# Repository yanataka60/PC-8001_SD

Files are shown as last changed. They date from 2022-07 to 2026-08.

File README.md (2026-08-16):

# PC-8001にSD-CARDからCMT形式ファイルのロード、セーブ機能

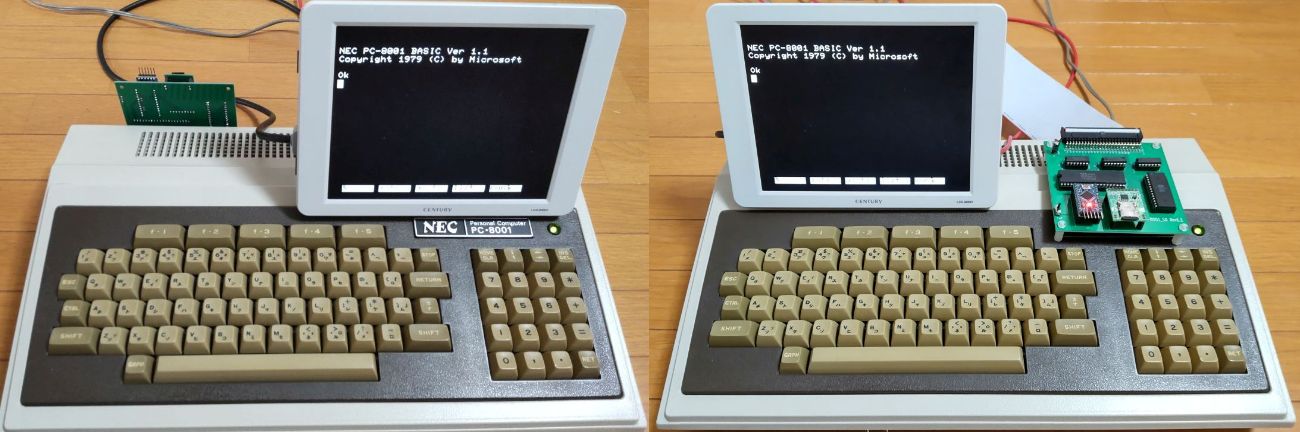
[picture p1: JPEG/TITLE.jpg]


　PC-8001でSD-CARDからCMT形式ファイルのロード、セーブ機能を実現するものです。

　CMTからの読み込み実行に数分掛かっていたゲームも数十秒で実行できます。

　接続は、PC-8001本体後ろの拡張端子に接続しますが、50pフラットケーブルでの接続、50pカードエッジコネクタでの接続のどちらかを選択できます。

　なお、Arduino、ROMへ書き込むための機器が別途必要となります。

## 回路図
　KiCadフォルダ内のPC-8001_SD.pdfを参照してください。

　J5 2x25Pinコネクタを追加しています。

[回路図](https://github.com/yanataka60/PC-8001_SD/blob/main/Kicad/PC-8001_SD.pdf)

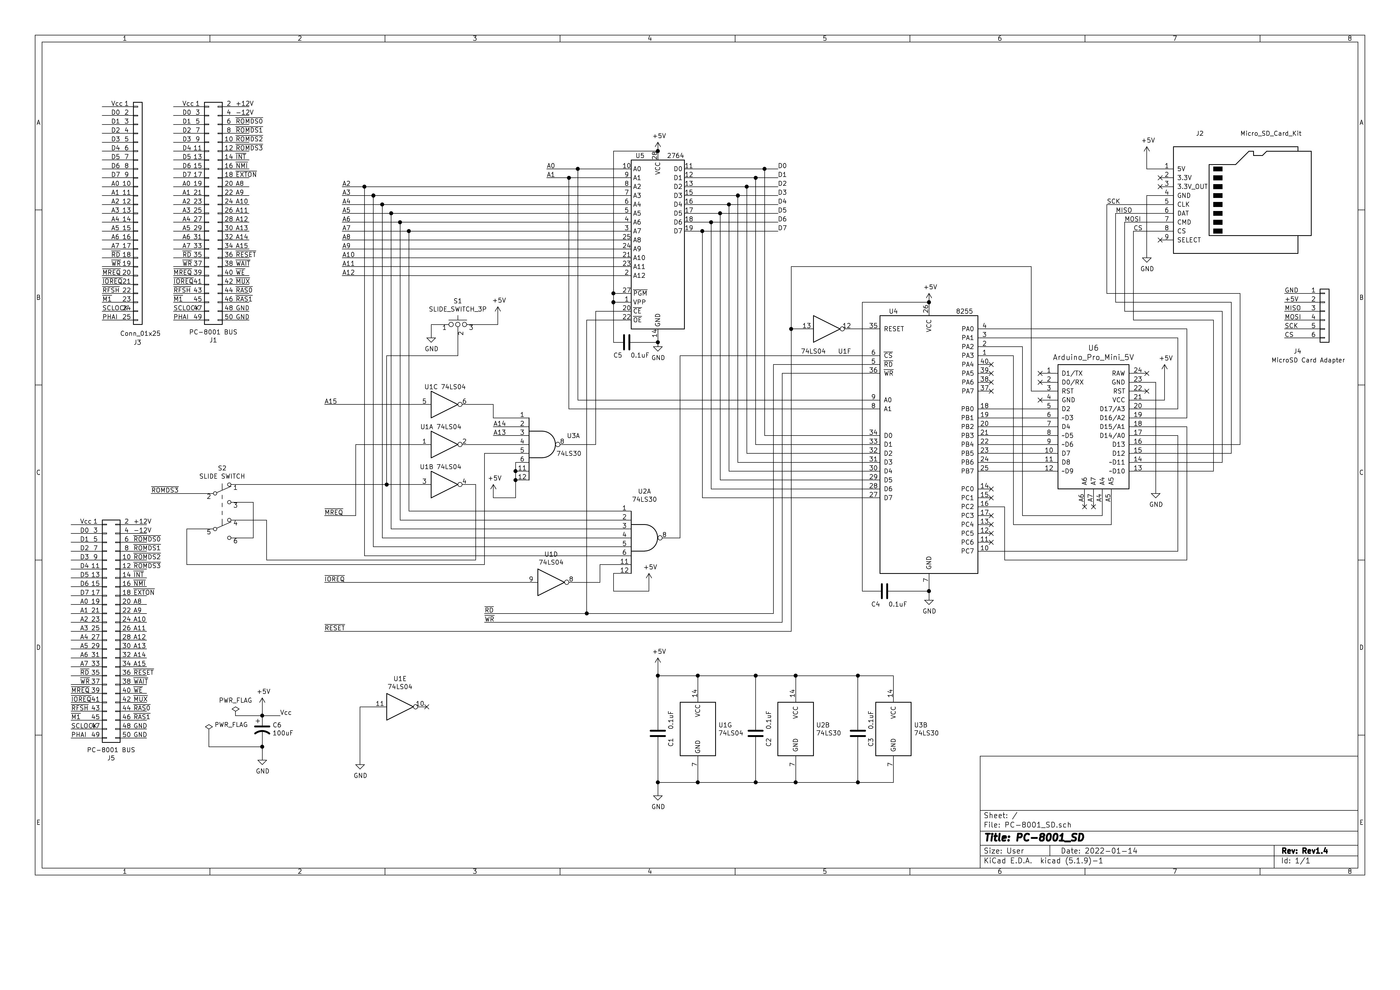
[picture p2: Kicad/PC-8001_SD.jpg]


## 部品
|番号|品名|数量|備考|
| --- | --- | --- | --- |
||J1、J3のいずれか|||
|J1|2x25ボックスヘッダ|1|共立エレショップ JS-1200R-50など、秋月電子通商 PH-2x40RGなどのピンヘッダでも代用可(注1)(注5)|
|J3|50Pカードエッジコネクタ|1|せんごくネット通販 HRS CR22A-50D-2.54DSなど(注1)|
||J2、J4のいずれか|||
|J2|Micro_SD_Card_Kit|1|秋月電子通商 AE-microSD-LLCNV (注2) (注4)|
|J4|MicroSD Card Adapter|1|Arduino等に使われる5V電源に対応したもの (注4)|
|U1|74LS04|1||
|U2 U3|74LS30|2||
|U4|8255|1||
|U5|2764/28C64相当品|1||
|U6|Arduino_Pro_Mini_5V|1|Atmega328版を使用 168版は不可。(注3)|
|C1-C5|積層セラミックコンデンサ 0.1uF|5||
|C6|電解コンデンサ 16v100uF|1||
|S1|3Pスライドスイッチ|1|秋月電子通商 SS12D01G4など|
|S2|２回路２接点 スライドスイッチ|1|秋月電子通商 IS-2235-Gなど|
||ピンヘッダ|2Pin分|Arduino_Pro_MiniにはA4、A5用のピンヘッダが付いていないため別途調達が必要です 秋月電子通商 PH-1x40SGなど|
||ピンソケット(任意)|26Pin分|Arduino_Pro_Miniを取り外し可能としたい場合に調達します 秋月電子通商 FHU-1x42SGなど|
|J5|2x25Pinコネクタ|1|秋月電子通商 PH-2x40SGなど(注1)|

　　　注1)J1又はJ3のどちらかを選択して取り付けてください。

　　　注2)秋月電子通商　AE-microSD-LLCNVのJ1ジャンパはショートしてください。

　　　注3)Arduino Pro MiniはA4、A5ピンも使っています。

　　　注4)J2又はJ4のどちらかを選択して取り付けてください。

　　　注5)ピンヘッダで代用するときは、基板から若干浮かせてピンヘッダをハンダ付けするとフラットケーブをスムーズに抜き差しできます。

### MicroSD Card Adapterを使う
J4に取り付けます。

MicroSD Card Adapterについているピンヘッダを除去してハンダ付けするのが一番確実ですが、J4の穴にMicroSD Card Adapterをぴったりと押しつけ、裏から多めにハンダを流し込むことでハンダ付けをする方法もあります。なお、この方法の時にはしっかりハンダ付けが出来たかテスターで導通を確認しておいた方が安心です。

ハンダ付けに自信のない方はJ2の秋月電子通商　AE-microSD-LLCNVをお使いください。AE-microSD-LLCNVならパワーLED、アクセスLEDが付いています。

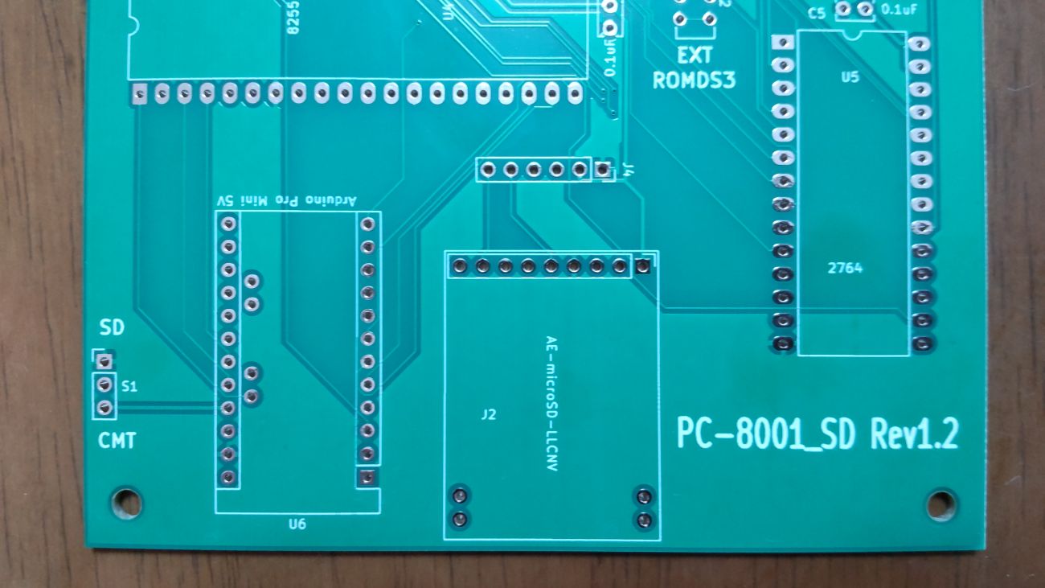
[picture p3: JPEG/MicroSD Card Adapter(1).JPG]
MicroSD Card Adapter1


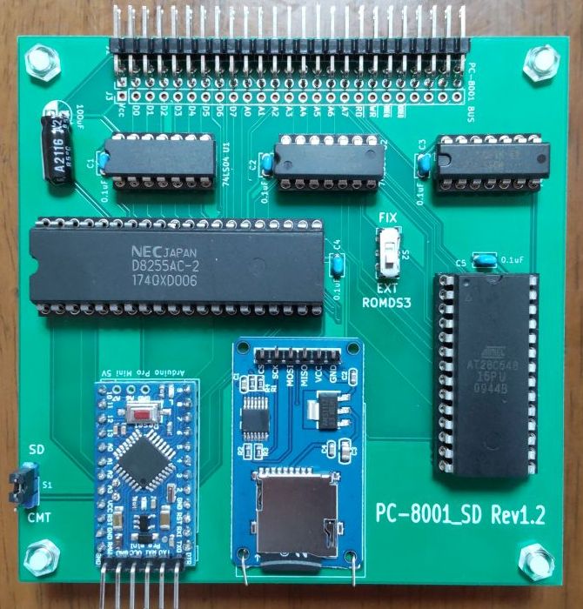
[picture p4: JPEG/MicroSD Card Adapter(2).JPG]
MicroSD Card Adapter2


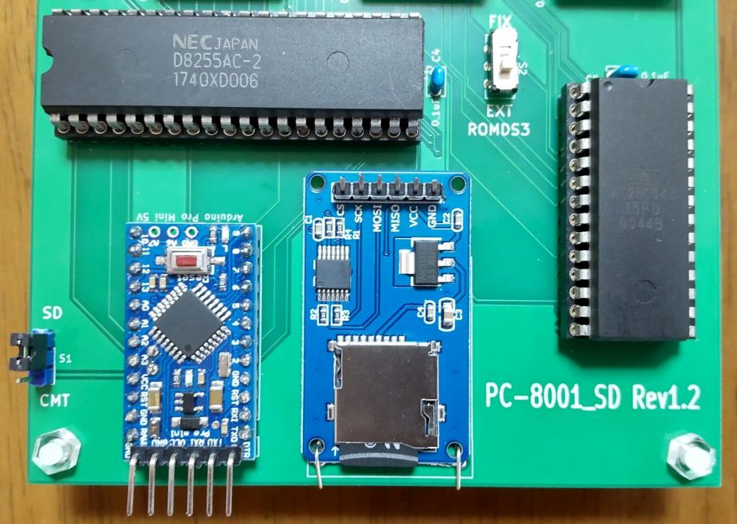
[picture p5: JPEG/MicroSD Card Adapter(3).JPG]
MicroSD Card Adapter3


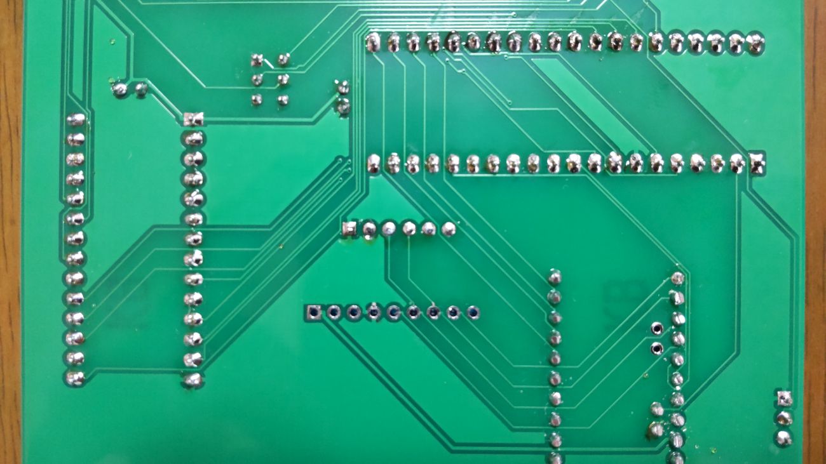
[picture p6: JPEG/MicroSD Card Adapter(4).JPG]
MicroSD Card Adapter4


### その他必要なもの
　2x25Pinコネクタ(J1)を取り付けた場合には、本体との接続用ケーブルが必要となります。

　片側が2.54mmピッチ2x25Pinメスコネクタ、片側が2.54mmピッチ50pカードエッジコネクタのフラットケーブルを用意してください。

## ROMへの書込み
　Z80フォルダ内のEXT_ROM.binをROMライター(TL866II Plus等)を使って2764又は28C64に書き込みます。

## Arduinoプログラム
　Arduino IDEを使ってArduinoフォルダのPC-8001_SDフォルダ内PC-8001_SD.inoを書き込みます。

　SdFatライブラリを使用しているのでArduino IDEメニューのライブラリの管理からライブラリマネージャを立ち上げて「SdFat」をインストールしてください。

　「SdFat」で検索すれば見つかります。「SdFat」と「SdFat - Adafruit Fork」が見つかりますが「SdFat」のほうを使っています。

注)Arduinoを基板に直付けしている場合、Arduinoプログラムを書き込むときは、PC-8001本体とは接続を外し、74LS04を外したうえで書き込んでください。

## コネクタの取り付け
### 2x25Pinコネクタ(J1)を取り付ける場合
　取付穴は外側から１列目と２列目を使います。基板の表側に取り付けます。
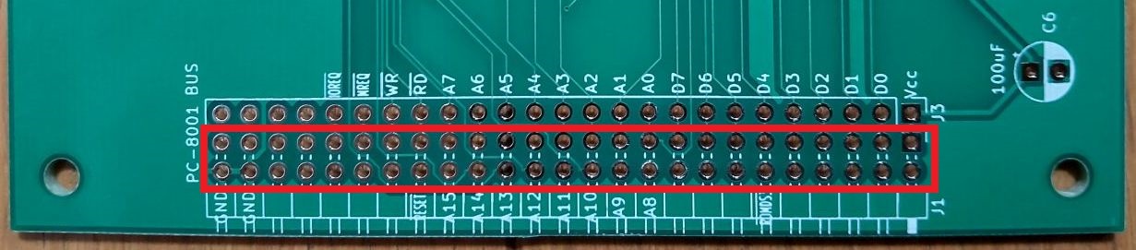
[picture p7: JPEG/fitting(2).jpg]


### 50Pカードエッジコネクタ(J3)を取り付ける場合
　取付穴は外側から１列目と３列目を使います。基板の裏側に取り付けます。
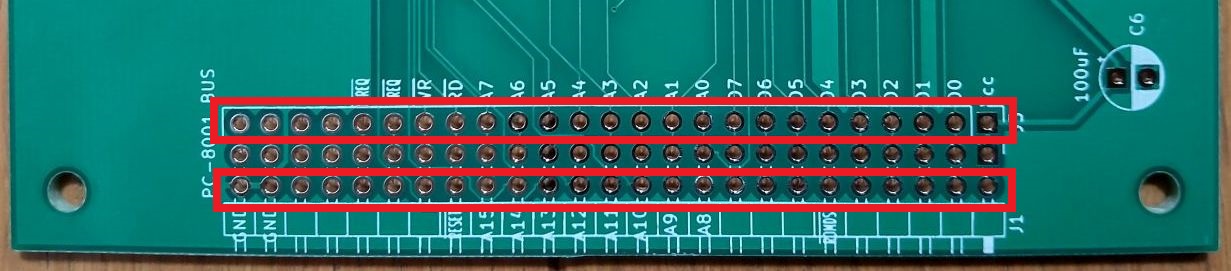
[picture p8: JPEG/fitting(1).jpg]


## 接続
　PC-8001本体後ろの拡張端子に接続します。

#### 注)PC-8001本体後ろの拡張端子は経年劣化により接触不良となることが非常に多いです。動作不良の場合は一度、拡張端子を消しゴムで擦る、アルコールで拭く等掃除をしてみてください。

### フラットケーブルによる接続
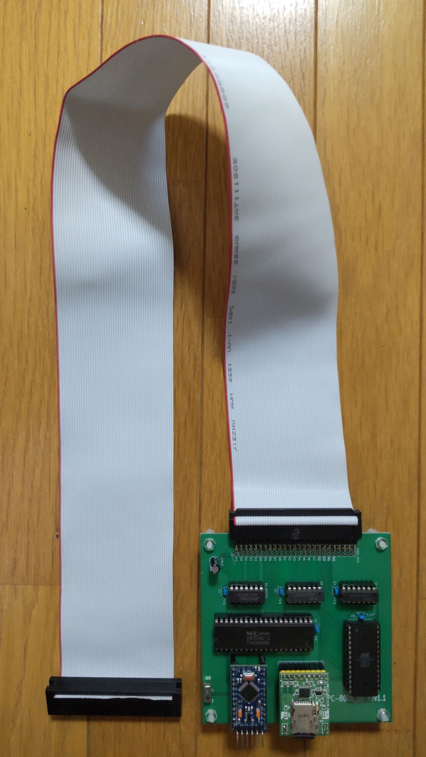
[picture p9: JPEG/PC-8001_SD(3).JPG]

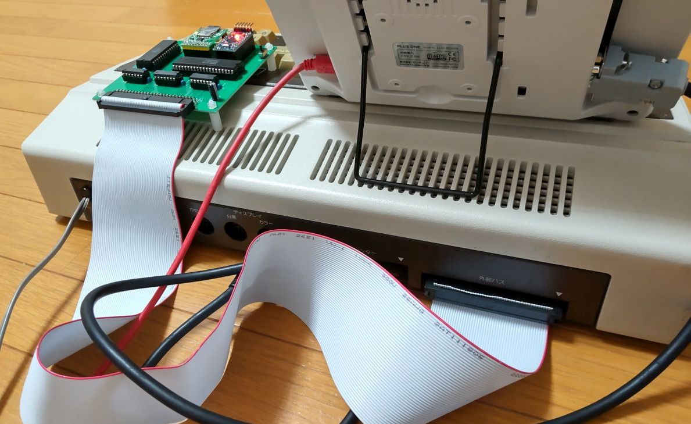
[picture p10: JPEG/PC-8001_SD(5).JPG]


### カードエッジコネクタによる接続
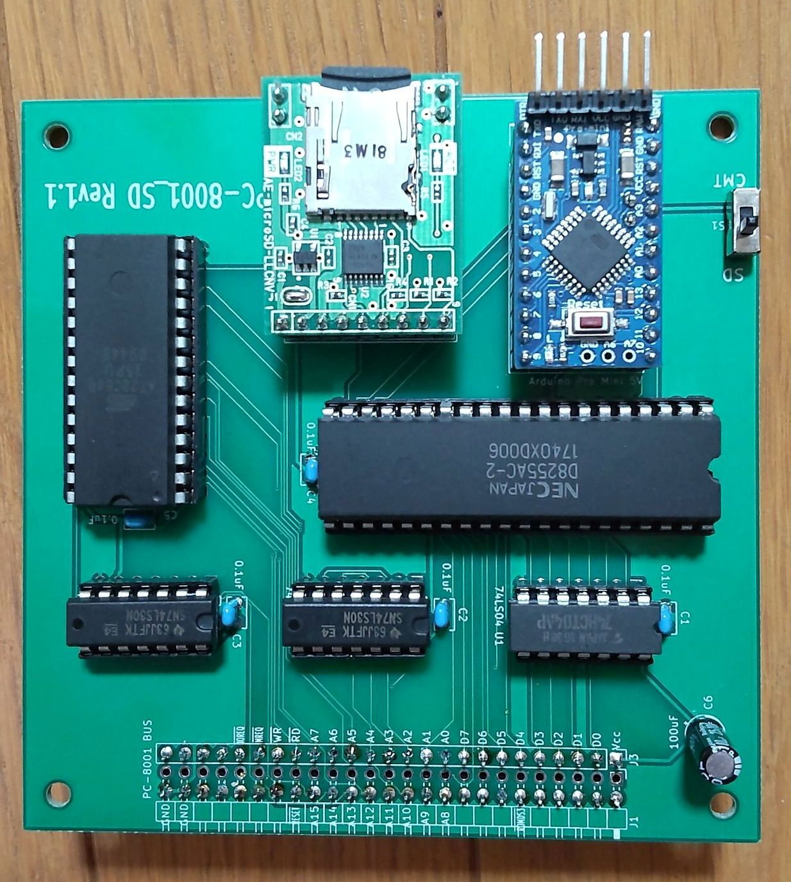
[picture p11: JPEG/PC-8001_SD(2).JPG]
Card Edge Connector1

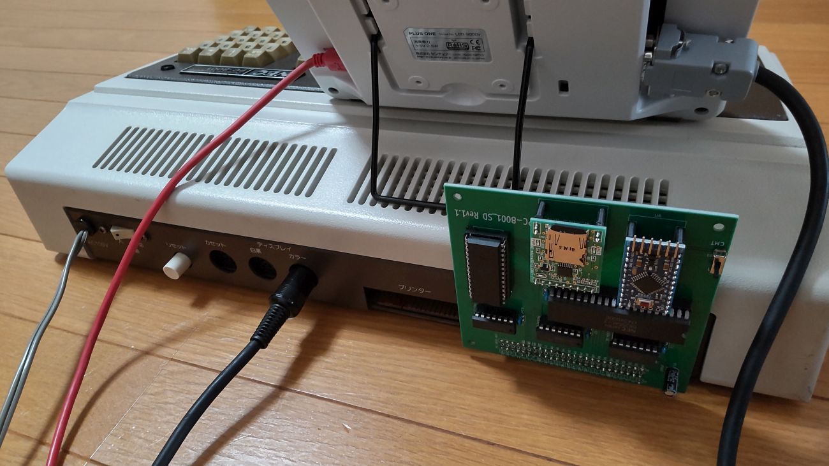
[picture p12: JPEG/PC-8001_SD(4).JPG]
Card Edge Connector2


#### 私の入手したカードエッジコネクタでは基板と本体の間が充分に離れていますが、カードエッジコネクタによっては接触の危険があるかもしれません。気になる方はカプトンテープなどで裏面を保護してください。

## J5 2x25Pinコネクタを使ってRAMボード等接続する場合
　J5 2x25Pinコネクタは、拡張端子と同じ配列です。フラットケーブルを接続してRAMボード等を接続できますが、接続する向きを間違えないようにしてください。
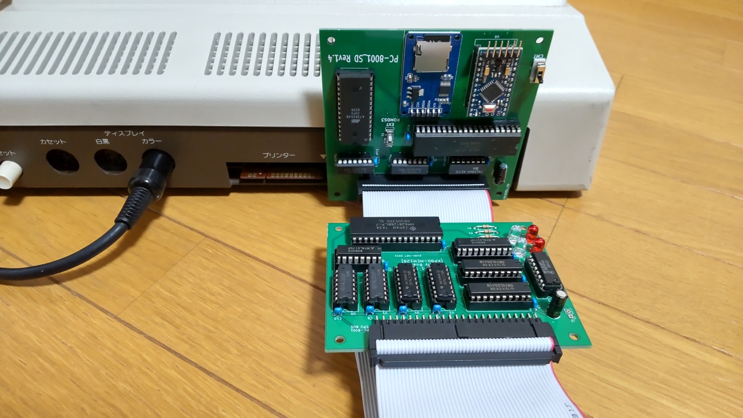
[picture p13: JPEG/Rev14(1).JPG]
Rev14_1

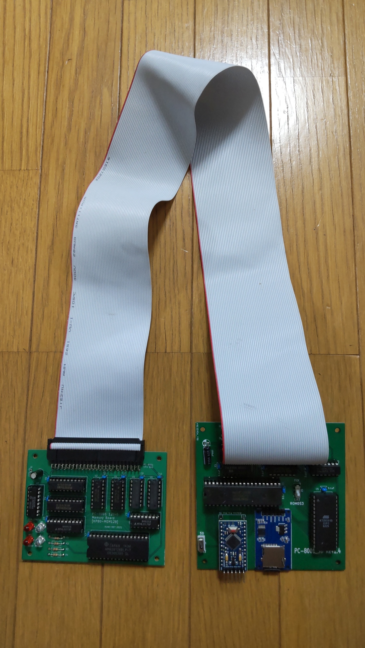
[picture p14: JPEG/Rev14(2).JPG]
Rev14_2

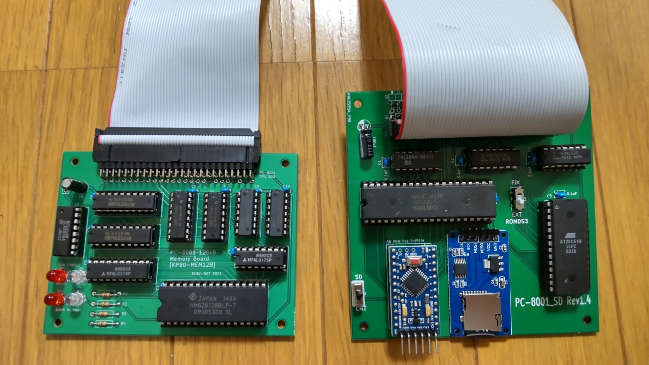
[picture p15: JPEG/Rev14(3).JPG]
Rev14_3


## SD-CARD
　出来れば8GB以下のSDカードを用意してください。

　ArduinoのSdFatライブラリは、SD規格(最大2GB)、SDHC規格(2GB～32GB)に対応していますが、SDXC規格(32GB～2TB)には対応していません。

　また、SDHC規格のSDカードであっても32GB、16GBは相性により動作しないものがあるようです。

　FAT16又はFAT32が認識できます。NTFSは認識できません。

　ルートに置かれた拡張子が「.CMT」のCMT形式ファイルのみ認識できます。(CMT形式以外のファイル、フォルダも表示されますがLOAD実行の対象になりません)

　CMT形式であれば複数のCMTファイルを一つのファイルとしてまとめてあっても認識します。

　例)

　　BASIC+機械語　　　　　　　　　　　　　->　LOAD "DOSファイル名"[CR]、MON[CR]、L[CR]

　　機械語+機械語　　　　　　　　　　　　->　MON[CR]、 L DOSファイル名[CR]、L[CR]

　　オートラン機能ファイル+BASIC　　　　　->　MON[CR]、L DOSファイル名[CR]（以下オートラン）

　　オートラン機能ファイル+BASIC+機械語　->　MON[CR]、L DOSファイル名[CR]（以下オートラン）

　　オートラン機能ファイル+機械語+機械語　->　MON[CR]、L DOSファイル名[CR]（以下オートラン）

　　など

　ファイル名は「.CMT」を含めて31文字まで、ただし半角カタカナ、及び一部の記号はArduinoが認識しないので使えません。パソコンでファイル名を付けるときはアルファベット、数字および空白でファイル名をつけてください。

## 使い方

PC-8001_SDを使いたくない時には、PC-8001_SDを外してしまうのが簡単ですが、SHIFTキーを押してまま電源ON又はRESETすると拡張ROMは無効となります。

なお、N-BASIC Ver1.0で動作させるには起動直後に「DEF USR=&H6003:A=USR(0)」を実行してください。

### BASICコマンド
#### FILES[CR]又はFILES "文字列"[CR]
FILES[CR]とするとSD-CARDルートディレクトリにあるファイルの一覧を表示します。

FILES "文字列"[CR]とするとSD-CARDルートディレクトリにあるその文字列から始まるファイルの一覧を表示します。

20件表示したところで指示待ちになるので打ち切るならESC又は↑を入力すると打ち切られ、Bキーで前の16件に戻ります。それ以外のキーで次の16件を表示します。

　行頭に「LOAD "」を付加して表示してあるので実行したいファイルにカーソルキーを合わせて[CR]キーを押すだけでLOAD可能です。

　表示される順番は、登録順となりファイル名アルファベッド順などのソートした順で表示することはできません。

##### 参考
　FILES "文字列"[CR]とする場合、基本的にはダブルコーテーションが無くても機能しますが、数字で始まるファイル名の場合ダブルコーテーションが無いと検索できません。

　× FILES 3

　○ FILES "3"

#### LOAD "DOSファイル名"[CR]
指定したDOSフィル名のBASICプログラムをSD-CARDからLOADします。

ファイル名の前に"(ダブルコーテーション)は必須ですが、ファイル名の後ろに"(ダブルコーテーション)は有っても無くても構いません。

ファイル名の最後の「.CMT」も有っても無くても構いません。

　例)

　　LOAD "TEST" -> DOSファイル名「TEST.CMT」を読み込みます。

　　LOAD "TEST.BAS" -> DOSファイル名「TEST.BAS.CMT」を読み込みます。

　　LOAD "TEST.BAS.CMT" -> DOSファイル名「TEST.BAS.CMT」を読み込みます。

##### 参考
　基本的にはDOSファイル名をダブルコーテーションで括らなくても機能しますが、数字で始まるファイル名の場合ダブルコーテーションが無いとLOADできません。

　NOT FIND FILEと表示されます。

　× LOAD 3D MAZE

　○ LOAD "3D MAZE"

#### LOAD ""[CR]（※多段ロードファイルの２段目以降のみ有効）
直前に読み込まれたDOSファイルが多段ロード用に複数のCMTファイルが連結されており、２段目以降がBASICプログラムであった時のみ有効に動作し、BASICプログラムをSD-CARDからLOADします。

#### SAVE "DOSファイル名"[CR]
BASICプログラムを指定したDOSフィル名でSD-CARDに上書きSAVEします。

ファイル名の省略は出来ません。

ファイル名の前に"(ダブルコーテーション)は必須ですが、ファイル名の後ろに"(ダブルコーテーション)は有っても無くても構いません。

ファイル名の最後の「.CMT」も有っても無くても構いません。

指定したDOSファイル名の最初の６文字がCMT形式の中に保存されるファイル名として使われます。

BASICプログラムであることを識別するために「.BAS」を付けることを推奨します。

　例)

　　SAVE "TEST" -> 「TEST.CMT」で保存される。

　　SAVE "TEST.BAS" -> 「TEST.BAS.CMT」で保存される。

##### 参考
　基本的にはDOSファイル名をダブルコーテーションで括らなくても機能しますが、数字で始まるファイル名の場合ダブルコーテーションが無いとSAVEできません。

　SD-CARD INITIALIZE ERRORと表示されます。

#### KILL DOSファイル名[CR]
指定したDOSフィル名がSD-CARDに存在すればSD-CARDから削除します。

ファイル名の最後に「.CMT」も指定してもしなくても構いません。

##### 参考
　基本的にはDOSファイル名をダブルコーテーションで括らなくても機能しますが、数字で始まるファイル名の場合ダブルコーテーションが無いとKILLできません。

　NOT FIND FILEと表示されます。

　× KILL 3D MAZE

　○ KILL "3D MAZE"

### MONITORコマンド
#### F[CR]又はF 文字列[CR]
文字列を入力せずにF[CR]のみ入力するとSD-CARDルートディレクトリにあるファイルの一覧を表示します。

文字列を付けて入力すればSD-CARDルートディレクトリにあるその文字列から始まるファイルの一覧を表示します。

20件表示したところで指示待ちになるので打ち切るならESC又は↑を入力すると打ち切られ、Bキーで前の16件に戻ります。それ以外のキーで次の16件を表示します。

　行頭に「*L 」を付加して表示してあるので実行したいファイルにカーソルキーを合わせて[CR]キーを押すだけでLOAD可能です。

　表示される順番は、登録順となりファイル名アルファベッド順などのソートした順で表示することはできません。

##### 例)
　　F[CR]

　　F S[CR]

　　F SP[CR]

#### L DOSファイル名[CR]
指定したDOSフィル名の機械語プログラムをSD-CARDからLOADします。

ファイル名の最後の「.CMT」は有っても無くても構いません。

　例)

　　L TEST -> DOSファイル名「TEST.CMT」を読み込みます。

　　L TEST.BIN -> DOSファイル名「TEST.BIN.CMT」を読み込みます。

　　L TEST.BIN.CMT -> DOSファイル名「TEST.BIN.CMT」を読み込みます。

#### L[CR]（※多段ロードファイルの２段目以降のみ有効）
直前に読み込まれたDOSファイルが多段ロード用に複数のCMTファイルが連結されており、２段目以降が機械語プログラムであった時のみ有効に動作し、機械語プログラムをSD-CARDからLOADします。

#### W 16進数4桁 16進数4桁 DOSファイル名[CR]
1番目の16進数4桁が表すアドレスから2番目の16進数4桁が表すアドレスまでを指定したDOSファイル名でSD-CARDに機械語として上書き保存します。

ファイル名の最後に「.CMT」を指定してもしなくても構いません。

またWの後ろや各パラメータ間に空白が有っても無くても構いません。

機械語プログラムであることを識別するために「.BIN」等を付けることを推奨します。

　例)

　　W 0000 001F TEST -> 　　0000番地から001F番地までをDOSファイル名「TEST.CMT」で保存する。

　　W 0000 001F TEST.BIN -> 0000番地から001F番地までをDOSファイル名「TEST.BIN.CMT」で保存する。

#### G 16進数4桁[CR]
16進数4桁が表すアドレスにジャンプします。

Gの後ろに空白があっても無くても構いません。

#### B[CR]
BASICに復帰します。MONITORでのコマンド入力をスクリーンエディタにしたため、CTRL+Bが機能しないので代替コマンドです。

CTRL+Cと動作は同じです。

#### CTRL+C
BASICに復帰します。MONITORでのコマンド入力をスクリーンエディタにしたため、CTRL+Bが機能しないので代替コマンドです。

B[CR]と動作は同じです。

#### S 16進数4桁 {16進数2桁}の繰り返し[CR]
PC-8001のメモリに16進数4桁が表すアドレスから16進数2桁が表すデータを書き込みます。

[CR]で改行すると有効な16進数2桁データを書き込んだ後、次に書き込みとなるアドレスを表示しますので続きの16進数2桁のデータを入力して[CR]で改行します。

アドレス表示の次に16進数2桁のデータを入力せずに[CR]を押すと終了します。

Sの後ろ、アドレス、データの区切りに空白が有っても無くても構いません。

例)

以下の例はすべて同じ結果となります。

　SA0001122334455

　SA000 11 22 33 44 55

　S A000 1122334455

　S A0001122334455

　S A000 1122 3344 55

#### D 16進数4桁[CR]
16進数4桁が表すアドレスからPC-8001のメモリの内容を128Byteを一画面として表示します。

一画面表示したところで「NEXT:ANY BACK:B BREAK:ESC」と表示して指示待ちとなるのでBで前の128Byteを表示、ESCで中止、それ以外のキーで次の128Byteの表示となります。

一画面表示している途中でもESCでいつでも中止できます。

### ファンクションキーを利用したオートラン機能
ファンクションキーを利用したオートラン機能に対応していますが、一部オリジナルと異なる点があります。

そこでオートラン機能ファイルをロードする時にPC-8001_SDの仕様に自動変換する機能を付けました。(2022.8.21実装)

以下の修正点についてオートラン機能ファイルをロードする時に自動的に修正ロードされますのでオートラン機能ファイルを修正する必要はありません。当然、修正してあっても機能します。

自動で修正される点

　1　CTRL+BではMONITORからBASICへ復帰できません。CTRL+Cに修正されます。

　2　SD-CARDからのBASICプログラムをLOADするコマンドは「LOAD」で、1本のCMTファイルとなっていればファイル名を指定する必要もありませんので「CLOAD"ファイル名"」は「LOAD""」に修正されます。

## 操作上の注意
　~~「SD-CARD INITIALIZE ERROR」と表示されたときは、SD-CARDをいったん抜き再挿入したうえでArduinoをリセットしてください。~~

　~~SD-CARDにアクセスしていない時に電源が入ったままで SD-CARDを抜いた後、再挿入しSD-CARDにアクセスすると「SD-CARD INITIALIZE ERROR」となる場合があります。再挿入した場合にはSD-CARDにアクセスする前にArduinoを必ずリセットしてください。~~

　~~SD-CARDの抜き差しは電源を切った状態で行うほうがより確実です。~~

　(2024.3.12) SD-CARDにアクセスしていない時に電源が入ったままでSD-CARDを抜くと再度SD-CARDを挿入してもSD-CARDにアクセスできない問題を解消しました。(Arduinoを最新版に書き換えてください)

　再度SD-CARDを挿入した後、FILES、LOAD、SAVE等でSD-CARDに3回ほどアクセスすれば復旧します。

## New City HeroをSDから読み込み実行するための修正
　PC-8001_SDは内藤 時浩さんが頒布されているNew City HeroをPC-8001実機で手軽に遊びたいが為に作ったといっても過言ではありません。

　New City Heroは機械語の多段ロード方式で２段目のプログラム内にCMTからの読み込みルーチンをコールしている箇所がありますので、そこをSDから読み込むためのコール先に修正する必要があります。

　New City HeroのCMT形式ファイルに次の手順で修正を行いPC-8001_SD用のCMT形式ファイルを作り、SD-CARDに保存してください。

　1　頒布していただいたNew City HeroのCMTファイルをbugfire2009さんの「DumpListEditor」にDrag&Dropする

　2　「BASIC入力」タブをクリックして言語「Patch File」を選択する。

　3　表示されているPathc File Sampleをすべて削除し、次の15行に入れ替える。

/CD,F3,0B/=00,00,00

/CD,9E,5F/=CD,06,60

/CD,9E,5F/=CD,06,60

/CD,9E,5F/=CD,06,60

/CD,9E,5F/=CD,06,60

/CD,9E,5F/=CD,06,60

/CD,9E,5F/=CD,06,60

/CD,9E,5F/=CD,06,60

/CD,9E,5F/=CD,06,60

/CD,9E,5F/=CD,06,60

/CD,9E,5F/=CD,06,60

/CD,9E,5F/=CD,06,60

/CD,9E,5F/=CD,06,60

/CD,9E,5F/=CD,06,60

/CD,9E,5F/=CD,06,60

　4　「ファイル整理画面にPaste」を押す。

　5　ファイル整理画面に「PATCH.patch」というファイルが追加される。ファイルの位置はどこにあっても可。

　6　「cmt書出し」を押してPC-8001_SD対応済cmtファイルとして保存する。

## DumpListEditor動画作成機で作られたCMTファイルへの対応

　DumpListEditor動画作成機で作られたCMTファイルのうち、「Chain(cmt出力時のみ)」をチェックして作られたプログラムはCMTルーチンをコールしますので修正が必要となります。

セミグラ作成機＆動画作成機

https://bugfire2009.ojaru.jp/semigra/

で紹介されているきらびぃさん作成の

「メガCD版シルフィードのデモをPC8001で再生してみたフル版(修正版)」

「PC8001でBad Apple全編をcmt化」

の二つがこの機能を使っていますのでPC-8001_SDで再生するにはパッチ当てが必要になります。

　なお、以下の方法でPATCHを当てると最後のシーンが無限ループします。最後のファイルにはPATCHを当てないでおけば止まるのですが、手軽にPATCHを当てられますのでご容赦ください。

### 「メガCD版シルフィードのデモをPC8001で再生してみたフル版(修正版)」修正手順
　1　CMTファイルを「DumpListEditor」にDrag&Dropする。

　2　「BASIC入力」タブをクリックして言語「Patch File」を選択する。

　3　表示されているPathc File Sampleをすべて削除し、次の2行に入れ替える。

/CD,3A,5F,30/=CD,09,60,18

/E6,04,20,09/=E6,04,18,09

　4　「ファイル整理画面にPaste」を押す。

　5　ファイル整理画面に「PATCH.patch」というファイルが追加される。ファイルの位置はどこにあっても可。

　6　「cmt書出し」を押してPC-8001_SD対応済cmtファイルとして保存する。

### 「PC8001でBad Apple全編をcmt化」修正手順

　基本的に「メガCD版シルフィードのデモをPC8001で再生してみたフル版(修正版)」の修正手順と同じです。

## RAMボートとの共存について
　バンク切替をサポートした以下のRAMボートとの共存、動作確認済みです。

　　ちくらっぺさん設計の「32kB拡張RAM基板」

　　KUNI-NET元シソペさん設計の「PC-8001用 128kバイトメモリーボード」

#### PSA基板に増設する拡張メモリー基板で動作しないとの報告を頂きました。
#### PSA基板に増設する拡張メモリー基板の仕様を確認したところ、拡張ROM領域を単純にRAMに置き換えることを目的として設計されており、バンク切替動作をサポートしていないため共存できません。

　S2のROMDS3を「EXT」にすることでポートE2hを制御して$0000～$7FFFの空間をROM→RAM切替するボードと共存できます。

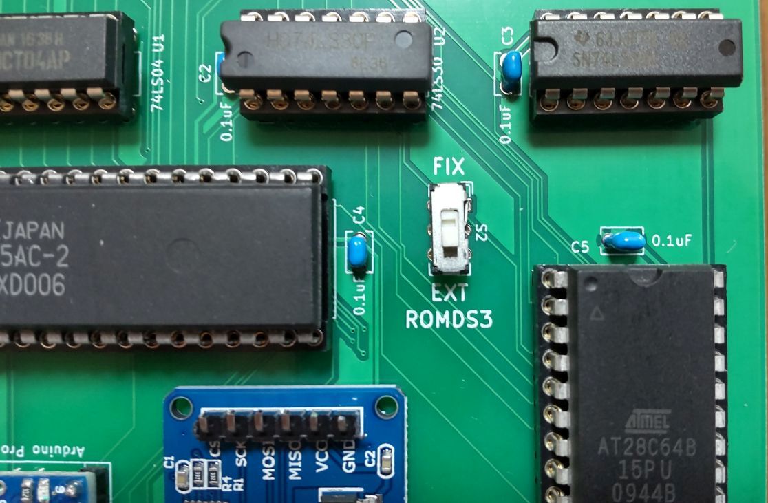
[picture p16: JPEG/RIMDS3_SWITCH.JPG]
RIMDS3_SWITCH


　S1のSD→CMT切替は機能しなくなりますが、どちらかにしておいてください。

　PC-8001_SDを繋いだままPC-8001_SDのROMを無効にしたい場合はS2のROMDS3を「FIX」、S1のSD→CMT切替を「CMT」にしてください。

## SDアクセスサービスルーチン
　「プログラム側からファイル名を指定してSDから読み込む」機能と「プログラム側からファイル名を指定してSDへ書き込む」機能を追加しました。

#### 　この機能を活用するには、この機能に対応したアプリケーションプログラムが必要となります。

　以下にサービスルーチンの仕様とエントリポイントを公開します。

|エントリポイント|名前|用途|
| --- | -- | -- |
|600F|ROPEN|READ FILE OPEN|

　HL <- DOS_FILENAME先頭アドレス

　HLレジスタが示すDOS_FILENAMEで読み込み用ファイルをオープン

　DOS_FILENAMEは31文字まで、最後に00Hをつけること。

　フラグレジスタ以外のレジスタは変化しない。

　正常終了 CF=0、異常終了 CF=1

|エントリポイント|名前|用途|
| --- | -- | -- |
|6006|D_5F9E|5F9EH代替|

　読み出されたデータ -> A

　読み込み用としてOPENしているファイルから1BYTE読み出し

|エントリポイント|名前|用途|
| --- | -- | -- |
|6009|H_5F3A|5F3AH代替|

　読み出しオープンされているファイルから機械語フォーマットで保存されている機械語を読み出す。

　WORK AREA:FF3D～FF3E メモリ書き込み開始アドレス

　正常終了 CF=0、異常終了 CF=1

|エントリポイント|名前|用途|
| --- | -- | -- |
|600C|MONHOT|5C66H代替|

　Gコマンドで実行する機械語プログラムからモニタに戻るときには、ここへのジャンプを指定。

　オートラン機能が実行中であれば継続して実行される。

|エントリポイント|名前|用途|
| --- | -- | -- |
|6012|WAOPEN|WRITE FILE APPEND OPEN|

　HL <- DOS_FILENAME先頭アドレス

　HLレジスタが示すDOS_FILENAMEで追加書き込み用としてファイルをオープン

　DOS_FILENAMEは31文字まで、最後に00Hをつけること。

　フラグレジスタ以外のレジスタは変化しない。

　正常終了 CF=0、異常終了 CF=1

|エントリポイント|名前|用途|
| --- | -- | -- |
|601B|WNOPEN|WRITE FILE NEW OPEN|

　HL <- DOS_FILENAME先頭アドレス

　HLレジスタが示すDOS_FILENAMEで書き込み用として新たにファイルをオープン。同名のDOS_FILENAMEのファイルがある場合は削除したのちにオープンする。

　DOS_FILENAMEは31文字まで、最後に00Hをつけること。

　フラグレジスタ以外のレジスタは変化しない。

　正常終了 CF=0、異常終了 CF=1

|エントリポイント|名前|用途|
| --- | -- | -- |
|6018|D_5F2F|5F2FH代替|

　A <- 書き込みデータ

　書込み用でオープンされているファイルにAレジスタのデータを追加書込みする。

　フラグレジスタ以外のレジスタは変化しない。

　正常終了 CF=0、異常終了 CF=1

|エントリポイント|名前|用途|
| --- | -- | -- |
|6015|D_5ED9|5ED9H代替|

　HL <- 書き込み開始アドレス

　DE <- 書き込み終了アドレス

　書込み用でオープンされているファイルに書き込み開始アドレスから書き込み終了アドレスまでのメモリ内容を機械語フォーマットで書出し、クローズする。

　WORK AREA:FF3D～FF3E 書き込み開始アドレス

　　　　　　　FF3F～FF40 書き込み終了アドレス

　正常終了 CF=0、異常終了 CF=1

|エントリポイント|名前|用途|
| --- | -- | -- |
|601E|WCLOSE|WRITE FILE CLOSE|

　書込み用ファイルをクローズする。

　フラグレジスタ以外のレジスタは変化しない。

　正常終了 CF=0、異常終了 CF=1

### SDアクセスサービスルーチンのテスト用プログラム
　SDアクセスサービスルーチンのテストと使い方のサンプルとしてZ80フォルダ内SD Access service routine Testフォルダにテストプログラムを置きました。

　「sd_test.BIN.CMT」と「SD_TEST2.BIN.CMT」の二つをSDカードにコピーしてモニタ Lコマンドで「sd_test.BIN.CMT」を読み込み実行してください。

　画面に01からFFまで表示した後、「SD TEST OK」と表示して終了します。

　SDカードには「SD_WRITE_READ_TEST.DAT」と「SD_WRT_DIRECT_TEST.BIN.CMT」の二つのファイルが出来上がっているはずです。

　「SD_WRITE_READ_TEST.DAT」は510Byteのファイルサイズで01からFF、FFから01までのデータが格納されているはずです。

　「SD_WRT_DIRECT_TEST.BIN.CMT」は161ByteのファイルサイズでA000h～A096hまでのメモリ内容を機械語フォーマットのcmtとして保存した内容となっているはずです。

## 謝辞
　基板の作成に当たり以下のデータを使わせていただきました。ありがとうございました。

　Arduino Pro Mini

　　https://github.com/g200kg/kicad-lib-arduino

　AE-microSD-LLCNV

　　https://github.com/kuninet/PC-8001-SD-8kRAM

　New City Heroの修正点を公開することを快く承諾してくださった内藤 時浩様、ありがとうございました。

　NBASICのコマンド追加に当たっては、ちくらっぺ様のSD-DOSがとても参考になりました。ありがとうございました。

　　https://github.com/chiqlappe/SD-DOS

　DumpListEditorの動画作成機で作成されたcmtファイルへの修正方法を公開することを快く承諾してくださったbugfire2009様、ありがとうございました。

　スタック領域を破壊し正常にロードが出来ない機械語プログラムの事例について情報を提供してくださった久保ちゃん様、ありがとうございました。

## 追記
2022.7.23

　BASICから機械語ファイルをLOADしようとしたときのエラーメッセージを修正しました。

2022.7.24

　FILES 文字列[CR]としたときにSYNTAX ERRORとなる事象を修正しました。これにより「FILSE SEARCH:」と聞いてくる仕様は廃止。

2022.7.25

　FILESを↑キーで打ち切ったとき、時々Syntax Errorが発生するため2行戻す動きを廃止

　FILES及びFコマンドの説明中誤りがあったので修正

　　一回で表示される行数　誤)20行　正)16行

　　打ち切るキー　誤)SHIFT+BREAK　正)ESC

2022.7.27

　DOSファイル名での拡張子について曖昧な記述があったので修正しました。

2022.8.4

　Arduinoを基板に直付けしている場合、Arduinoプログラムを書き込むときの注意点を書き加えました。

　Kicadライブラリ設定を修正しました。

　BASICでSyntax Errorが表示される事象に対応するためEXT_ROMプログラムに修正を加えました。

2022.8.14

　EXTROM.BINを修正

　　MONITOR Gコマンドの処理でPOP BCが抜けていたので追加。

　　mk2用と統合

　　　拡張ROM認識コードを041H,042H,00Hとした。

　　　SHIFTキーを押しながら起動することで拡張ROMを有効にするか選択できるようにした。(mk2用)

　　　mk2においてもfiles、save、killコマンドでSyntaxErrorが出ないように修正

2022.8.18

　DumpListEditorの動画作成機機能で作成されたきらびぃさん作成の「メガCD版シルフィードのデモをPC8001で再生してみたフル版(修正版)」、「PC8001でBad Apple全編をcmt化」の修正方法を追加しました。

2022.8.21

　MONITOR Lコマンドで読み込み時にオートラン機能ファイルであればCTRL+B、CLOADをSD用に書き換えるようにした。

2022.8.22

　N-BASIC Ver1.0では動作しない旨を追記、カードエッジコネクタでの接続時に裏面の保護について追記。

　N-BASIC Ver1.0で動作させる方法を追記。

2022.8.31

　RAMボードと共存するための改造方法を追記。

2022.9.18

　PSA基板に増設する拡張メモリー基板とは共存できないことを追記

2022.9.25

　MicroSD Card Adapter用の端子、ROMDS3制御切り替えスイッチを付加し、基板をRev1.2に更新。

2023.5.30

　E800h以降までロードする機械語プログラムをロードするとスタック領域を破壊してしまうことに対処。

2023.6.3

　mk2用ソースの修正のためEXT_ROM.sを修正。

2023.6.10

　SDアクセスサービスルーチンを追加、エントリポイントを公開。5F3AH代替ルーチンを見直し。

2023.8.11

　Rev1.4基板を追加しました。

2023.9.11

　N-BASIC V1.0の場合、MONITORに入ることでPC-8001_SDの初期化が行われるように修正。

2023.10.5

　ファイル名長さの仕様を訂正

　　誤)「.CMT」を除いて32文字      正)「.CMT」を含めて31文字

2024.1.15

　SDカードは8GB以下が望ましいことを追記。

2024.3.12

　電源が入ったままでSD-CARDを抜くと再度SD-CARDを挿入してもSD-CARDにアクセスできない問題を解消した。

2024.9.11

　サービスルーチンでの使用ワークエリアを追記

2025.1.29

　コネクタの記述を修正しました。

2025.8.15

　PC-8001本体後部拡張端子の接触不良について追記。PC-8001mk2_SDとのソースコード互換性確保のためN-BASICV1.0判別ルーチンを後ろに移動。

2025.8.30

　サービスルーチンで解説していなかった600Ch(MONHOT)の解説を追加。

2026.8.16

　旧基板用の記述を整理しました。

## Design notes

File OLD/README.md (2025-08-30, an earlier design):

# PC-8001にSD-CARDからCMT形式ファイルのロード、セーブ機能

PC-8001_SD

　PC-8001でSD-CARDからCMT形式ファイルのロード、セーブ機能を実現するものです。

　CMTからの読み込み実行に数分掛かっていたゲームも数十秒で実行できます。

　接続は、PC-8001本体後ろの拡張端子に接続しますが、50pフラットケーブルでの接続、50pカードエッジコネクタでの接続のどちらかを選択できます。

　なお、Arduino、ROMへ書き込むための機器が別途必要となります。

#### (2023.8.11)拡張端子と同じ配列の2x25Pinコネクタを追加したRev1.4基板を追加しました。これにより50pカードエッジコネクタで接続した時にもRAMボード等を接続できるようになります。

#### 注)N-BASIC Ver1.1で動作確認を行っていますが、N-BASIC Ver1.0では動作しないとの報告を頂きました。
#### 　　Ver1.0のバグにより拡張ROMの検出ができないため、PC-8001_SDの初期化がされないことが分かりました。
#### 　　(2023.9.11)N-BASIC Ver1.0で動作させるには起動直後に「MON」を実行し、MONITORに入ることでPC-8001_SDの初期化を行うようにしました。Bコマンド又はCTRL+CでBASICに戻ることでBASICからもPC-8001_SDが使えるようになります。

## 回路図
### Rev1.2
　KiCadフォルダ内のPC-8001_SD.pdfを参照してください。

[回路図](https://github.com/yanataka60/PC-8001_SD/blob/main/Kicad/PC-8001_SD.pdf)

PC-8001_SD

### Rev1.4
　KiCad1_4フォルダ内のPC-8001_SD.pdfを参照してください。

　J5 2x25Pinコネクタを追加しています。

[回路図](https://github.com/yanataka60/PC-8001_SD/blob/main/Kicad1_4/PC-8001_SD.pdf)

PC-8001_SD

## 部品
### Rev1.2
|番号|品名|数量|備考|
| --- | --- | --- | --- |
||J1、J3のいずれか|||
|J1|2x25ボックスヘッダ|1|共立エレショップ JS-1200R-50など、秋月電子通商 PH-2x40RGなどのピンヘッダでも代用可(注1)(注5)|
|J3|50Pカードエッジコネクタ|1|せんごくネット通販 HRS CR22A-50D-2.54DSなど(注1)|
||J2、J4のいずれか|||
|J2|Micro_SD_Card_Kit|1|秋月電子通商 AE-microSD-LLCNV (注2) (注4)|
|J4|MicroSD Card Adapter|1|Arduino等に使われる5V電源に対応したもの (注4)|
|U1|74LS04|1||
|U2 U3|74LS30|2||
|U4|8255|1||
|U5|2764/28C64相当品|1||
|U6|Arduino_Pro_Mini_5V|1|Atmega328版を使用 168版は不可。(注3)|
|C1-C5|積層セラミックコンデンサ 0.1uF|5||
|C6|電解コンデンサ 16v100uF|1||
|S1|3Pスライドスイッチ|1|秋月電子通商 SS12D01G4など|
|S2|２回路２接点 スライドスイッチ|1|秋月電子通商 IS-2235-Gなど|
||ピンヘッダ|2Pin分|Arduino_Pro_MiniにはA4、A5用のピンヘッダが付いていないため別途調達が必要です 秋月電子通商 PH-1x40SGなど|
||ピンソケット(任意)|26Pin分|Arduino_Pro_Miniを取り外し可能としたい場合に調達します 秋月電子通商 FHU-1x42SGなど|

　　　注1)J1又はJ3のどちらかを選択して取り付けてください。

　　　注2)秋月電子通商　AE-microSD-LLCNVのJ1ジャンパはショートしてください。

　　　注3)Arduino Pro MiniはA4、A5ピンも使っています。

　　　注4)J2又はJ4のどちらかを選択して取り付けてください。

　　　注5)ピンヘッダで代用するときは、基板から若干浮かせてピンヘッダをハンダ付けするとフラットケーブをスムーズに抜き差しできます。

### Rev1.4
Rev1.2基板に以下の部品が追加となります。
|番号|品名|数量|備考|
| --- | --- | --- | --- |
|J5|2x25Pinコネクタ|1|秋月電子通商 PH-2x40SGなど(注1)|

### MicroSD Card Adapterを使う(Rev1.2以上)
J4に取り付けます。

MicroSD Card Adapterについているピンヘッダを除去してハンダ付けするのが一番確実ですが、J4の穴にMicroSD Card Adapterをぴったりと押しつけ、裏から多めにハンダを流し込むことでハンダ付けをする方法もあります。なお、この方法の時にはしっかりハンダ付けが出来たかテスターで導通を確認しておいた方が安心です。

ハンダ付けに自信のない方はJ2の秋月電子通商　AE-microSD-LLCNVをお使いください。AE-microSD-LLCNVならパワーLED、アクセスLEDが付いています。

MicroSD Card Adapter1

MicroSD Card Adapter2

MicroSD Card Adapter3

MicroSD Card Adapter4

### MicroSD Card Adapterを使う(Rev1.1)
以下のピン番号を参考に変換基板等繋ぎ方は適宜対応してください。

|AE-microSD-LLCNVピン番号|MicroSD Card Adapterピン番号|信号名|
| --- | --- | ---- |
|1|2|5V|
|4|1|GND|
|5|5|SCK|
|6|3|MISO|
|7|4|MOSI|
|8|6|CS|

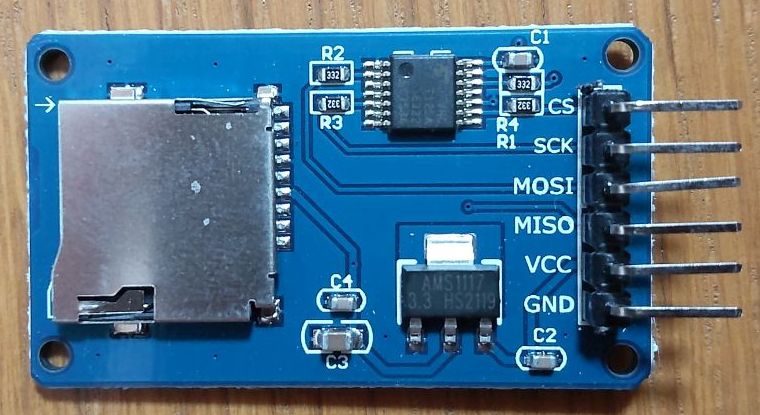
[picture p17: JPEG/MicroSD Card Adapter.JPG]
MicroSD Card Adapter


### その他必要なもの
　2x25Pinコネクタ(J1)を取り付けた場合には、本体との接続用ケーブルが必要となります。

　片側が2.54mmピッチ2x25Pinメスコネクタ、片側が2.54mmピッチ50pカードエッジコネクタのフラットケーブルを用意してください。

## ROMへの書込み
　Z80フォルダ内のEXT_ROM.binをROMライター(TL866II Plus等)を使って2764又は28C64に書き込みます。

## Arduinoプログラム
　Arduino IDEを使ってArduinoフォルダのPC-8001_SDフォルダ内PC-8001_SD.inoを書き込みます。

　SdFatライブラリを使用しているのでArduino IDEメニューのライブラリの管理からライブラリマネージャを立ち上げて「SdFat」をインストールしてください。

　「SdFat」で検索すれば見つかります。「SdFat」と「SdFat - Adafruit Fork」が見つかりますが「SdFat」のほうを使っています。

注)Arduinoを基板に直付けしている場合、Arduinoプログラムを書き込むときは、PC-8001本体とは接続を外し、74LS04を外したうえで書き込んでください。

## コネクタの取り付け
### 2x25Pinコネクタ(J1)を取り付ける場合
　取付穴は外側から１列目と２列目を使います。基板の表側に取り付けます。
Flat cable1

### 50Pカードエッジコネクタ(J3)を取り付ける場合
　取付穴は外側から１列目と３列目を使います。基板の裏側に取り付けます。
Flat cable2

## 接続
　PC-8001本体後ろの拡張端子に接続します。

#### 注)PC-8001本体後ろの拡張端子は経年劣化により接触不良となることが非常に多いです。動作不良の場合は一度、拡張端子を消しゴムで擦る、アルコールで拭く等掃除をしてみてください。

### フラットケーブルによる接続
Flat cable1
Flat cable2

### カードエッジコネクタによる接続
Card Edge Connector1
Card Edge Connector2

#### 私の入手したカードエッジコネクタでは基板と本体の間が充分に離れていますが、カードエッジコネクタによっては接触の危険があるかもしれません。気になる方はカプトンテープなどで裏面を保護してください。

## Rev1.4基板でJ5 2x25Pinコネクタを使ってRAMボード等接続する場合
　J5 2x25Pinコネクタは、拡張端子と同じ配列です。フラットケーブルを接続してRAMボード等を接続できますが、接続する向きを間違えないようにしてください。
Rev14_1
Rev14_2
Rev14_3

## SD-CARD
　出来れば8GB以下のSDカードを用意してください。

　ArduinoのSdFatライブラリは、SD規格(最大2GB)、SDHC規格(2GB～32GB)に対応していますが、SDXC規格(32GB～2TB)には対応していません。

　また、SDHC規格のSDカードであっても32GB、16GBは相性により動作しないものがあるようです。

　FAT16又はFAT32が認識できます。NTFSは認識できません。

　ルートに置かれた拡張子が「.CMT」のCMT形式ファイルのみ認識できます。(CMT形式以外のファイル、フォルダも表示されますがLOAD実行の対象になりません)

　CMT形式であれば複数のCMTファイルを一つのファイルとしてまとめてあっても認識します。

　例)

　　BASIC+機械語　　　　　　　　　　　　　->　LOAD "DOSファイル名"[CR]、MON[CR]、L[CR]

　　機械語+機械語　　　　　　　　　　　　->　MON[CR]、 L DOSファイル名[CR]、L[CR]

　　オートラン機能ファイル+BASIC　　　　　->　MON[CR]、L DOSファイル名[CR]（以下オートラン）

　　オートラン機能ファイル+BASIC+機械語　->　MON[CR]、L DOSファイル名[CR]（以下オートラン）

　　オートラン機能ファイル+機械語+機械語　->　MON[CR]、L DOSファイル名[CR]（以下オートラン）

　　など

　ファイル名は「.CMT」を含めて31文字まで、ただし半角カタカナ、及び一部の記号はArduinoが認識しないので使えません。パソコンでファイル名を付けるときはアルファベット、数字および空白でファイル名をつけてください。

## 使い方

PC-8001_SDを使いたくない時には、PC-8001_SDを外してしまうのが簡単ですが、SHIFTキーを押してまま電源ON又はRESETすると拡張ROMは無効となります。

なお、N-BASIC Ver1.0で動作させるには起動直後に「DEF USR=&H6003:A=USR(0)」を実行してください。

### BASICコマンド
#### FILES[CR]又はFILES "文字列"[CR]
FILES[CR]とするとSD-CARDルートディレクトリにあるファイルの一覧を表示します。

FILES "文字列"[CR]とするとSD-CARDルートディレクトリにあるその文字列から始まるファイルの一覧を表示します。

20件表示したところで指示待ちになるので打ち切るならESC又は↑を入力すると打ち切られ、Bキーで前の16件に戻ります。それ以外のキーで次の16件を表示します。

　行頭に「LOAD "」を付加して表示してあるので実行したいファイルにカーソルキーを合わせて[CR]キーを押すだけでLOAD可能です。

　表示される順番は、登録順となりファイル名アルファベッド順などのソートした順で表示することはできません。

##### 参考
　FILES "文字列"[CR]とする場合、基本的にはダブルコーテーションが無くても機能しますが、数字で始まるファイル名の場合ダブルコーテーションが無いと検索できません。

　× FILES 3

　○ FILES "3"

#### LOAD "DOSファイル名"[CR]
指定したDOSフィル名のBASICプログラムをSD-CARDからLOADします。

ファイル名の前に"(ダブルコーテーション)は必須ですが、ファイル名の後ろに"(ダブルコーテーション)は有っても無くても構いません。

ファイル名の最後の「.CMT」も有っても無くても構いません。

　例)

　　LOAD "TEST" -> DOSファイル名「TEST.CMT」を読み込みます。

　　LOAD "TEST.BAS" -> DOSファイル名「TEST.BAS.CMT」を読み込みます。

　　LOAD "TEST.BAS.CMT" -> DOSファイル名「TEST.BAS.CMT」を読み込みます。

##### 参考
　基本的にはDOSファイル名をダブルコーテーションで括らなくても機能しますが、数字で始まるファイル名の場合ダブルコーテーションが無いとLOADできません。

　NOT FIND FILEと表示されます。

　× LOAD 3D MAZE

　○ LOAD "3D MAZE"

#### LOAD ""[CR]（※多段ロードファイルの２段目以降のみ有効）
直前に読み込まれたDOSファイルが多段ロード用に複数のCMTファイルが連結されており、２段目以降がBASICプログラムであった時のみ有効に動作し、BASICプログラムをSD-CARDからLOADします。

#### SAVE "DOSファイル名"[CR]
BASICプログラムを指定したDOSフィル名でSD-CARDに上書きSAVEします。

ファイル名の省略は出来ません。

ファイル名の前に"(ダブルコーテーション)は必須ですが、ファイル名の後ろに"(ダブルコーテーション)は有っても無くても構いません。

ファイル名の最後の「.CMT」も有っても無くても構いません。

指定したDOSファイル名の最初の６文字がCMT形式の中に保存されるファイル名として使われます。

BASICプログラムであることを識別するために「.BAS」を付けることを推奨します。

　例)

　　SAVE "TEST" -> 「TEST.CMT」で保存される。

　　SAVE "TEST.BAS" -> 「TEST.BAS.CMT」で保存される。

##### 参考
　基本的にはDOSファイル名をダブルコーテーションで括らなくても機能しますが、数字で始まるファイル名の場合ダブルコーテーションが無いとSAVEできません。

　SD-CARD INITIALIZE ERRORと表示されます。

#### KILL DOSファイル名[CR]
指定したDOSフィル名がSD-CARDに存在すればSD-CARDから削除します。

ファイル名の最後に「.CMT」も指定してもしなくても構いません。

##### 参考
　基本的にはDOSファイル名をダブルコーテーションで括らなくても機能しますが、数字で始まるファイル名の場合ダブルコーテーションが無いとKILLできません。

　NOT FIND FILEと表示されます。

　× KILL 3D MAZE

　○ KILL "3D MAZE"

### MONITORコマンド
#### F[CR]又はF 文字列[CR]
文字列を入力せずにF[CR]のみ入力するとSD-CARDルートディレクトリにあるファイルの一覧を表示します。

文字列を付けて入力すればSD-CARDルートディレクトリにあるその文字列から始まるファイルの一覧を表示します。

20件表示したところで指示待ちになるので打ち切るならESC又は↑を入力すると打ち切られ、Bキーで前の16件に戻ります。それ以外のキーで次の16件を表示します。

　行頭に「*L 」を付加して表示してあるので実行したいファイルにカーソルキーを合わせて[CR]キーを押すだけでLOAD可能です。

　表示される順番は、登録順となりファイル名アルファベッド順などのソートした順で表示することはできません。

##### 例)
　　F[CR]

　　F S[CR]

　　F SP[CR]

#### L DOSファイル名[CR]
指定したDOSフィル名の機械語プログラムをSD-CARDからLOADします。

ファイル名の最後の「.CMT」は有っても無くても構いません。

　例)

　　L TEST -> DOSファイル名「TEST.CMT」を読み込みます。

　　L TEST.BIN -> DOSファイル名「TEST.BIN.CMT」を読み込みます。

　　L TEST.BIN.CMT -> DOSファイル名「TEST.BIN.CMT」を読み込みます。

#### L[CR]（※多段ロードファイルの２段目以降のみ有効）
直前に読み込まれたDOSファイルが多段ロード用に複数のCMTファイルが連結されており、２段目以降が機械語プログラムであった時のみ有効に動作し、機械語プログラムをSD-CARDからLOADします。

#### W 16進数4桁 16進数4桁 DOSファイル名[CR]
1番目の16進数4桁が表すアドレスから2番目の16進数4桁が表すアドレスまでを指定したDOSファイル名でSD-CARDに機械語として上書き保存します。

ファイル名の最後に「.CMT」を指定してもしなくても構いません。

またWの後ろや各パラメータ間に空白が有っても無くても構いません。

機械語プログラムであることを識別するために「.BIN」等を付けることを推奨します。

　例)

　　W 0000 001F TEST -> 　　0000番地から001F番地までをDOSファイル名「TEST.CMT」で保存する。

　　W 0000 001F TEST.BIN -> 0000番地から001F番地までをDOSファイル名「TEST.BIN.CMT」で保存する。

#### G 16進数4桁[CR]
16進数4桁が表すアドレスにジャンプします。

Gの後ろに空白があっても無くても構いません。

#### B[CR]
BASICに復帰します。MONITORでのコマンド入力をスクリーンエディタにしたため、CTRL+Bが機能しないので代替コマンドです。

CTRL+Cと動作は同じです。

#### CTRL+C
BASICに復帰します。MONITORでのコマンド入力をスクリーンエディタにしたため、CTRL+Bが機能しないので代替コマンドです。

B[CR]と動作は同じです。

#### S 16進数4桁 {16進数2桁}の繰り返し[CR]
PC-8001のメモリに16進数4桁が表すアドレスから16進数2桁が表すデータを書き込みます。

[CR]で改行すると有効な16進数2桁データを書き込んだ後、次に書き込みとなるアドレスを表示しますので続きの16進数2桁のデータを入力して[CR]で改行します。

アドレス表示の次に16進数2桁のデータを入力せずに[CR]を押すと終了します。

Sの後ろ、アドレス、データの区切りに空白が有っても無くても構いません。

例)

以下の例はすべて同じ結果となります。

　SA0001122334455

　SA000 11 22 33 44 55

　S A000 1122334455

　S A0001122334455

　S A000 1122 3344 55

#### D 16進数4桁[CR]
16進数4桁が表すアドレスからPC-8001のメモリの内容を128Byteを一画面として表示します。

一画面表示したところで「NEXT:ANY BACK:B BREAK:ESC」と表示して指示待ちとなるのでBで前の128Byteを表示、ESCで中止、それ以外のキーで次の128Byteの表示となります。

一画面表示している途中でもESCでいつでも中止できます。

### ファンクションキーを利用したオートラン機能
ファンクションキーを利用したオートラン機能に対応していますが、一部オリジナルと異なる点があります。

そこでオートラン機能ファイルをロードする時にPC-8001_SDの仕様に自動変換する機能を付けました。(2022.8.21実装)

以下の修正点についてオートラン機能ファイルをロードする時に自動的に修正ロードされますのでオートラン機能ファイルを修正する必要はありません。当然、修正してあっても機能します。

自動で修正される点

　1　CTRL+BではMONITORからBASICへ復帰できません。CTRL+Cに修正されます。

　2　SD-CARDからのBASICプログラムをLOADするコマンドは「LOAD」で、1本のCMTファイルとなっていればファイル名を指定する必要もありませんので「CLOAD"ファイル名"」は「LOAD""」に修正されます。

## 操作上の注意
　~~「SD-CARD INITIALIZE ERROR」と表示されたときは、SD-CARDをいったん抜き再挿入したうえでArduinoをリセットしてください。~~

　~~SD-CARDにアクセスしていない時に電源が入ったままで SD-CARDを抜いた後、再挿入しSD-CARDにアクセスすると「SD-CARD INITIALIZE ERROR」となる場合があります。再挿入した場合にはSD-CARDにアクセスする前にArduinoを必ずリセットしてください。~~

　~~SD-CARDの抜き差しは電源を切った状態で行うほうがより確実です。~~

　(2024.3.12) SD-CARDにアクセスしていない時に電源が入ったままでSD-CARDを抜くと再度SD-CARDを挿入してもSD-CARDにアクセスできない問題を解消しました。(Arduinoを最新版に書き換えてください)

　再度SD-CARDを挿入した後、FILES、LOAD、SAVE等でSD-CARDに3回ほどアクセスすれば復旧します。

## New City HeroをSDから読み込み実行するための修正
　PC-8001_SDは内藤 時浩さんが頒布されているNew City HeroをPC-8001実機で手軽に遊びたいが為に作ったといっても過言ではありません。

　New City Heroは機械語の多段ロード方式で２段目のプログラム内にCMTからの読み込みルーチンをコールしている箇所がありますので、そこをSDから読み込むためのコール先に修正する必要があります。

　New City HeroのCMT形式ファイルに次の手順で修正を行いPC-8001_SD用のCMT形式ファイルを作り、SD-CARDに保存してください。

#### 2023.6.10 DumpListEditorのPatch File機能で作る方法に修正しました。

~~1　頒布していただいたNew City HeroのCMTファイルをbugfire2009さんの「DumpListEditor」にDrag&Dropする~~

~~2　表示される3つのBINファイルをうち、2番目のBINファイルを「マシン語入力に送る」を押す~~

~~3 「CD F3 0B」を検索して「00 00 00」に修正(1箇所)~~

~~4 「9E 5F」を検索して「06 60」に修正(14箇所)~~

~~5　v1.1.1の場合、「9E 5F」の検索では13箇所しか見つからないので「CD 9E」で検索し、「9E」を「06」に次行最初の「5F」を「60」に修正(1箇所)~~

~~6　修正が終わったら「ファイル整理画面にPaste」を押す~~

~~7　ファイル整理画面に戻ったことを確認し、「cmt書出し」を押してPC-8001_SD対応済cmtファイルとして保存する~~

　1　頒布していただいたNew City HeroのCMTファイルをbugfire2009さんの「DumpListEditor」にDrag&Dropする

　2　「BASIC入力」タブをクリックして言語「Patch File」を選択する。

　3　表示されているPathc File Sampleをすべて削除し、次の15行に入れ替える。

/CD,F3,0B/=00,00,00

/CD,9E,5F/=CD,06,60

/CD,9E,5F/=CD,06,60

/CD,9E,5F/=CD,06,60

/CD,9E,5F/=CD,06,60

/CD,9E,5F/=CD,06,60

/CD,9E,5F/=CD,06,60

/CD,9E,5F/=CD,06,60

/CD,9E,5F/=CD,06,60

/CD,9E,5F/=CD,06,60

/CD,9E,5F/=CD,06,60

/CD,9E,5F/=CD,06,60

/CD,9E,5F/=CD,06,60

/CD,9E,5F/=CD,06,60

/CD,9E,5F/=CD,06,60

　4　「ファイル整理画面にPaste」を押す。

　5　ファイル整理画面に「PATCH.patch」というファイルが追加される。ファイルの位置はどこにあっても可。

　6　「cmt書出し」を押してPC-8001_SD対応済cmtファイルとして保存する。

## DumpListEditor動画作成機で作られたCMTファイルへの対応

　DumpListEditor動画作成機で作られたCMTファイルのうち、「Chain(cmt出力時のみ)」をチェックして作られたプログラムはCMTルーチンをコールしますので修正が必要となります。

セミグラ作成機＆動画作成機

https://bugfire2009.ojaru.jp/semigra/

で紹介されているきらびぃさん作成の

「メガCD版シルフィードのデモをPC8001で再生してみたフル版(修正版)」

「PC8001でBad Apple全編をcmt化」

の二つがこの機能を使っていますのでPC-8001_SDで再生するにはパッチ当てが必要になります。

　なお、以下の方法でPATCHを当てると最後のシーンが無限ループします。最後のファイルにはPATCHを当てないでおけば止まるのですが、手軽にPATCHを当てられますのでご容赦ください。

### 「メガCD版シルフィードのデモをPC8001で再生してみたフル版(修正版)」修正手順
　1　CMTファイルを「DumpListEditor」にDrag&Dropする。

　2　「BASIC入力」タブをクリックして言語「Patch File」を選択する。

　3　表示されているPathc File Sampleをすべて削除し、次の2行に入れ替える。

/CD,3A,5F,30/=CD,09,60,18

/E6,04,20,09/=E6,04,18,09

　4　「ファイル整理画面にPaste」を押す。

　5　ファイル整理画面に「PATCH.patch」というファイルが追加される。ファイルの位置はどこにあっても可。

　6　「cmt書出し」を押してPC-8001_SD対応済cmtファイルとして保存する。

### 「PC8001でBad Apple全編をcmt化」修正手順

　基本的に「メガCD版シルフィードのデモをPC8001で再生してみたフル版(修正版)」の修正手順と同じです。

#### 2023.6.10 「メガCD版シルフィードのデモをPC8001で再生してみたフル版(修正版)」と同じ手順で動くようになりました。

~~ですが、「PC8001でBad Apple全編をcmt化」には「EA68-EAD4.BIN」が最初に一つしかありません。~~

~~CMTでは問題なく動作しますが、PC-8001_SDではLOADだけで止まってしまいますので「EA68-EAD4.BIN」を「メガCD版シルフィードのデモをPC8001で再生してみたフル版(修正版)」のように一つ置きにコピー＆ペーストします。~~

~~終わったら『2　「BASIC入力」タブをクリックして言語「Patch File」を選択する。』以降を行ってください。~~

## RAMボートとの共存について
　バンク切替をサポートした以下のRAMボートとの共存、動作確認済みです。

　　ちくらっぺさん設計の「32kB拡張RAM基板」

　　KUNI-NET元シソペさん設計の「PC-8001用 128kバイトメモリーボード」

#### PSA基板に増設する拡張メモリー基板で動作しないとの報告を頂きました。
#### PSA基板に増設する拡張メモリー基板の仕様を確認したところ、拡張ROM領域を単純にRAMに置き換えることを目的として設計されており、バンク切替動作をサポートしていないため共存できません。

### Rev1.2以上での対応
　S2のROMDS3を「EXT」にすることでポートE2hを制御して$0000～$7FFFの空間をROM→RAM切替するボードと共存できます。

RIMDS3_SWITCH

　S1のSD→CMT切替は機能しなくなりますが、どちらかにしておいてください。

　PC-8001_SDを繋いだままPC-8001_SDのROMを無効にしたい場合はS2のROMDS3を「FIX」、S1のSD→CMT切替を「CMT」にしてください。

### Rev1.1での対応
　ポートE2hを制御して$0000～$7FFFの空間をROM→RAM切替するボードと共存するにはパターンカットとジャンパ線の追加による改造が必要となります。

　本体内拡張ROM用ICソケットに挿入されたROMとの共存を考慮した設計だったのですが、RAMボードとの共存には裏目に出てしまいました。

　ですのでこの改造を行うとスイッチによるSD→CMTの切替又は、本体内拡張ROM用ICソケットに挿入されたROMとの切替は出来なくなりますので承知の上改造願います。

|パターンカット箇所|
| ---------------------- |
|ROMDS3(コネクタ12pin)から74LS04 3pinへ|
|74LS04 4pinから74LS30 5pinへ|

|ジャンパ線|
| ---------------------- |
|ROMDS3(コネクタ12pin)から74LS30 5pinへ|

なお、3Pスライドスイッチは意味をなさなくなりますが撤去するとLS04の入力が不定となるので撤去する必要はありません。撤去するのであれば3Pスライドスイッチの中点とGNDをジャンパしてLowレベルに固定してください。

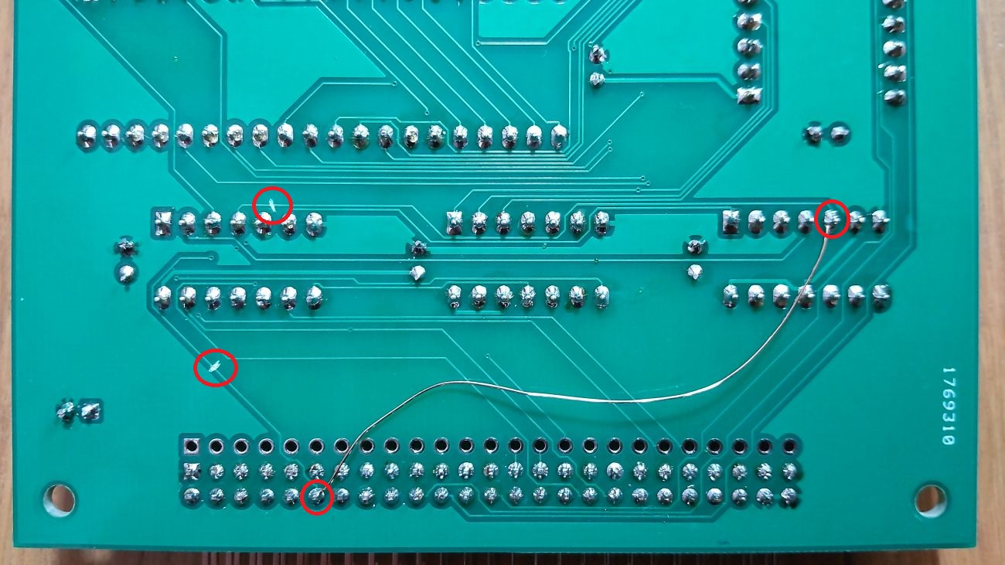
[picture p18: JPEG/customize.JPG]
customize


## SDアクセスサービスルーチン
　「プログラム側からファイル名を指定してSDから読み込む」機能と「プログラム側からファイル名を指定してSDへ書き込む」機能を追加しました。

#### 　この機能を活用するには、この機能に対応したアプリケーションプログラムが必要となります。

　以下にサービスルーチンの仕様とエントリポイントを公開します。

|エントリポイント|名前|用途|
| --- | -- | -- |
|600F|ROPEN|READ FILE OPEN|

　HL <- DOS_FILENAME先頭アドレス

　HLレジスタが示すDOS_FILENAMEで読み込み用ファイルをオープン

　DOS_FILENAMEは31文字まで、最後に00Hをつけること。

　フラグレジスタ以外のレジスタは変化しない。

　正常終了 CF=0、異常終了 CF=1

|エントリポイント|名前|用途|
| --- | -- | -- |
|6006|D_5F9E|5F9EH代替|

　読み出されたデータ -> A

　読み込み用としてOPENしているファイルから1BYTE読み出し

|エントリポイント|名前|用途|
| --- | -- | -- |
|6009|H_5F3A|5F3AH代替|

　読み出しオープンされているファイルから機械語フォーマットで保存されている機械語を読み出す。

　WORK AREA:FF3D～FF3E メモリ書き込み開始アドレス

　正常終了 CF=0、異常終了 CF=1

|エントリポイント|名前|用途|
| --- | -- | -- |
|600C|MONHOT|5C66H代替|

　Gコマンドで実行する機械語プログラムからモニタに戻るときには、ここへのジャンプを指定。

　オートラン機能が実行中であれば継続して実行される。

|エントリポイント|名前|用途|
| --- | -- | -- |
|6012|WAOPEN|WRITE FILE APPEND OPEN|

　HL <- DOS_FILENAME先頭アドレス

　HLレジスタが示すDOS_FILENAMEで追加書き込み用としてファイルをオープン

　DOS_FILENAMEは31文字まで、最後に00Hをつけること。

　フラグレジスタ以外のレジスタは変化しない。

　正常終了 CF=0、異常終了 CF=1

|エントリポイント|名前|用途|
| --- | -- | -- |
|601B|WNOPEN|WRITE FILE NEW OPEN|

　HL <- DOS_FILENAME先頭アドレス

　HLレジスタが示すDOS_FILENAMEで書き込み用として新たにファイルをオープン。同名のDOS_FILENAMEのファイルがある場合は削除したのちにオープンする。

　DOS_FILENAMEは31文字まで、最後に00Hをつけること。

　フラグレジスタ以外のレジスタは変化しない。

　正常終了 CF=0、異常終了 CF=1

|エントリポイント|名前|用途|
| --- | -- | -- |
|6018|D_5F2F|5F2FH代替|

　A <- 書き込みデータ

　書込み用でオープンされているファイルにAレジスタのデータを追加書込みする。

　フラグレジスタ以外のレジスタは変化しない。

　正常終了 CF=0、異常終了 CF=1

|エントリポイント|名前|用途|
| --- | -- | -- |
|6015|D_5ED9|5ED9H代替|

　HL <- 書き込み開始アドレス

　DE <- 書き込み終了アドレス

　書込み用でオープンされているファイルに書き込み開始アドレスから書き込み終了アドレスまでのメモリ内容を機械語フォーマットで書出し、クローズする。

　WORK AREA:FF3D～FF3E 書き込み開始アドレス

　　　　　　　FF3F～FF40 書き込み終了アドレス

　正常終了 CF=0、異常終了 CF=1

|エントリポイント|名前|用途|
| --- | -- | -- |
|601E|WCLOSE|WRITE FILE CLOSE|

　書込み用ファイルをクローズする。

　フラグレジスタ以外のレジスタは変化しない。

　正常終了 CF=0、異常終了 CF=1

### SDアクセスサービスルーチンのテスト用プログラム
　SDアクセスサービスルーチンのテストと使い方のサンプルとしてZ80フォルダ内SD Access service routine Testフォルダにテストプログラムを置きました。

　「sd_test.BIN.CMT」と「SD_TEST2.BIN.CMT」の二つをSDカードにコピーしてモニタ Lコマンドで「sd_test.BIN.CMT」を読み込み実行してください。

　画面に01からFFまで表示した後、「SD TEST OK」と表示して終了します。

　SDカードには「SD_WRITE_READ_TEST.DAT」と「SD_WRT_DIRECT_TEST.BIN.CMT」の二つのファイルが出来上がっているはずです。

　「SD_WRITE_READ_TEST.DAT」は510Byteのファイルサイズで01からFF、FFから01までのデータが格納されているはずです。

　「SD_WRT_DIRECT_TEST.BIN.CMT」は161ByteのファイルサイズでA000h～A096hまでのメモリ内容を機械語フォーマットのcmtとして保存した内容となっているはずです。

## 謝辞
　基板の作成に当たり以下のデータを使わせていただきました。ありがとうございました。

　Arduino Pro Mini

　　https://github.com/g200kg/kicad-lib-arduino

　AE-microSD-LLCNV

　　https://github.com/kuninet/PC-8001-SD-8kRAM

　New City Heroの修正点を公開することを快く承諾してくださった内藤 時浩様、ありがとうございました。

　NBASICのコマンド追加に当たっては、ちくらっぺ様のSD-DOSがとても参考になりました。ありがとうございました。

　　https://github.com/chiqlappe/SD-DOS

　DumpListEditorの動画作成機で作成されたcmtファイルへの修正方法を公開することを快く承諾してくださったbugfire2009様、ありがとうございました。

　スタック領域を破壊し正常にロードが出来ない機械語プログラムの事例について情報を提供してくださった久保ちゃん様、ありがとうございました。

## 追記
2022.7.23

　BASICから機械語ファイルをLOADしようとしたときのエラーメッセージを修正しました。

2022.7.24

　FILES 文字列[CR]としたときにSYNTAX ERRORとなる事象を修正しました。これにより「FILSE SEARCH:」と聞いてくる仕様は廃止。

2022.7.25

　FILESを↑キーで打ち切ったとき、時々Syntax Errorが発生するため2行戻す動きを廃止

　FILES及びFコマンドの説明中誤りがあったので修正

　　一回で表示される行数　誤)20行　正)16行

　　打ち切るキー　誤)SHIFT+BREAK　正)ESC

2022.7.27

　DOSファイル名での拡張子について曖昧な記述があったので修正しました。

2022.8.4

　Arduinoを基板に直付けしている場合、Arduinoプログラムを書き込むときの注意点を書き加えました。

　Kicadライブラリ設定を修正しました。

　BASICでSyntax Errorが表示される事象に対応するためEXT_ROMプログラムに修正を加えました。

2022.8.14

　EXTROM.BINを修正

　　MONITOR Gコマンドの処理でPOP BCが抜けていたので追加。

　　mk2用と統合

　　　拡張ROM認識コードを041H,042H,00Hとした。

　　　SHIFTキーを押しながら起動することで拡張ROMを有効にするか選択できるようにした。(mk2用)

　　　mk2においてもfiles、save、killコマンドでSyntaxErrorが出ないように修正

2022.8.18

　DumpListEditorの動画作成機機能で作成されたきらびぃさん作成の「メガCD版シルフィードのデモをPC8001で再生してみたフル版(修正版)」、「PC8001でBad Apple全編をcmt化」の修正方法を追加しました。

2022.8.21

　MONITOR Lコマンドで読み込み時にオートラン機能ファイルであればCTRL+B、CLOADをSD用に書き換えるようにした。

2022.8.22

　N-BASIC Ver1.0では動作しない旨を追記、カードエッジコネクタでの接続時に裏面の保護について追記。

　N-BASIC Ver1.0で動作させる方法を追記。

2022.8.31

　RAMボードと共存するための改造方法を追記。

2022.9.18

　PSA基板に増設する拡張メモリー基板とは共存できないことを追記

2022.9.25

　MicroSD Card Adapter用の端子、ROMDS3制御切り替えスイッチを付加し、基板をRev1.2に更新。

2023.5.30

　E800h以降までロードする機械語プログラムをロードするとスタック領域を破壊してしまうことに対処。

2023.6.3

　mk2用ソースの修正のためEXT_ROM.sを修正。

2023.6.10

　SDアクセスサービスルーチンを追加、エントリポイントを公開。5F3AH代替ルーチンを見直し。

2023.8.11

　Rev1.4基板を追加しました。

2023.9.11

　N-BASIC V1.0の場合、MONITORに入ることでPC-8001_SDの初期化が行われるように修正。

2023.10.5

　ファイル名長さの仕様を訂正

　　誤)「.CMT」を除いて32文字      正)「.CMT」を含めて31文字

2024.1.15

　SDカードは8GB以下が望ましいことを追記。

2024.3.12

　電源が入ったままでSD-CARDを抜くと再度SD-CARDを挿入してもSD-CARDにアクセスできない問題を解消した。

2024.9.11

　サービスルーチンでの使用ワークエリアを追記

2025.1.29

　コネクタの記述を修正しました。

2025.8.15

　PC-8001本体後部拡張端子の接触不良について追記。PC-8001mk2_SDとのソースコード互換性確保のためN-BASICV1.0判別ルーチンを後ろに移動。

2025.8.30

　サービスルーチンで解説していなかった600Ch(MONHOT)の解説を追加。

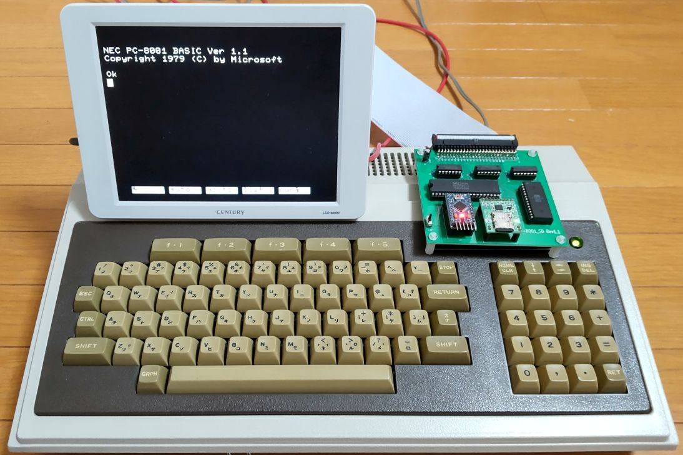
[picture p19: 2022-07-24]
JPEG/PC-8001_SD(1).JPG

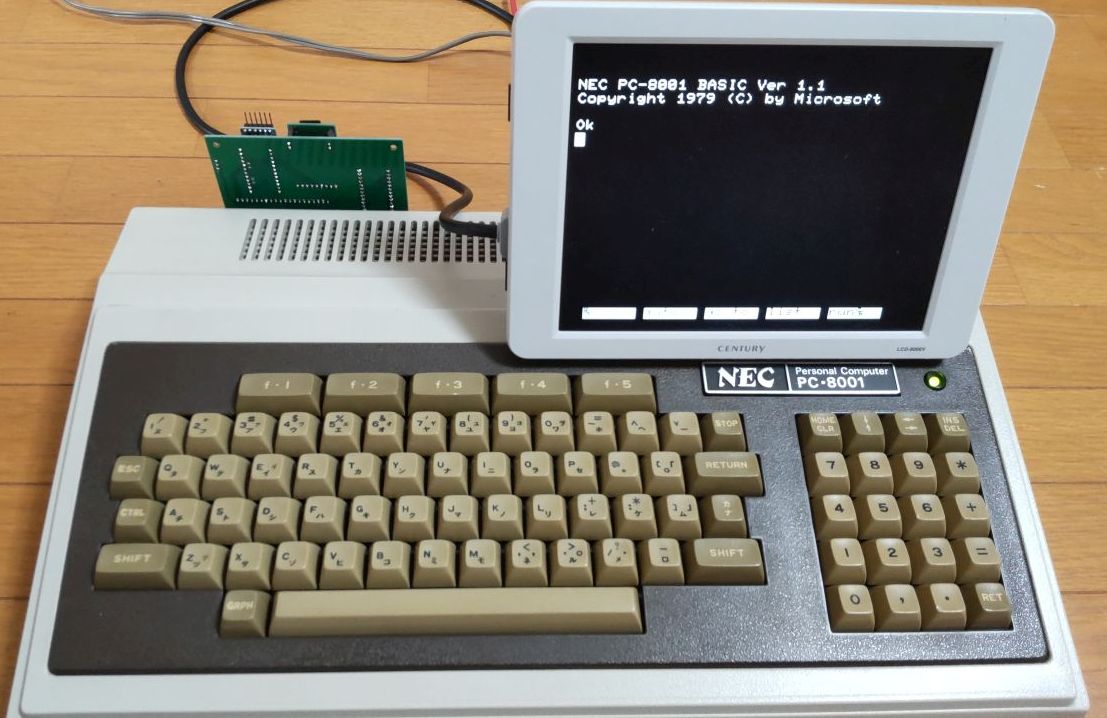
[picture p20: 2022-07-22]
JPEG/PC-8001_SD(0).JPG

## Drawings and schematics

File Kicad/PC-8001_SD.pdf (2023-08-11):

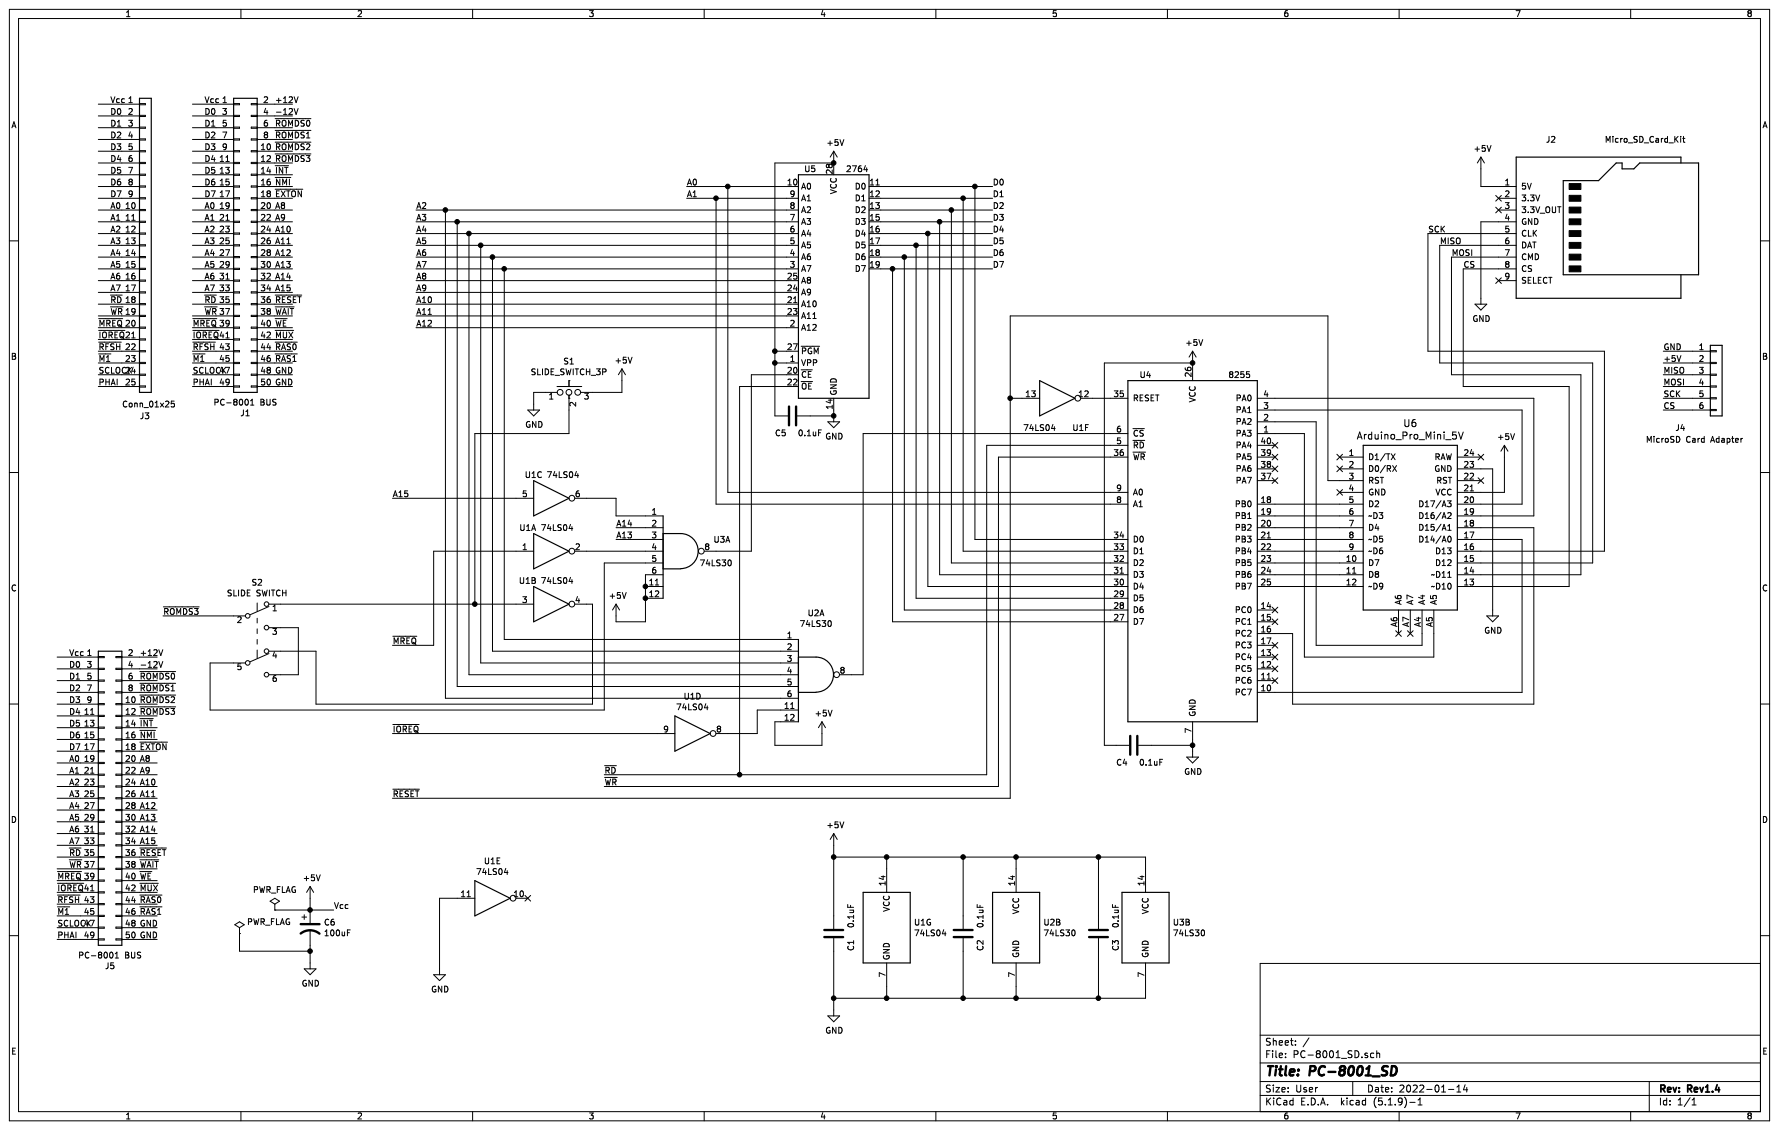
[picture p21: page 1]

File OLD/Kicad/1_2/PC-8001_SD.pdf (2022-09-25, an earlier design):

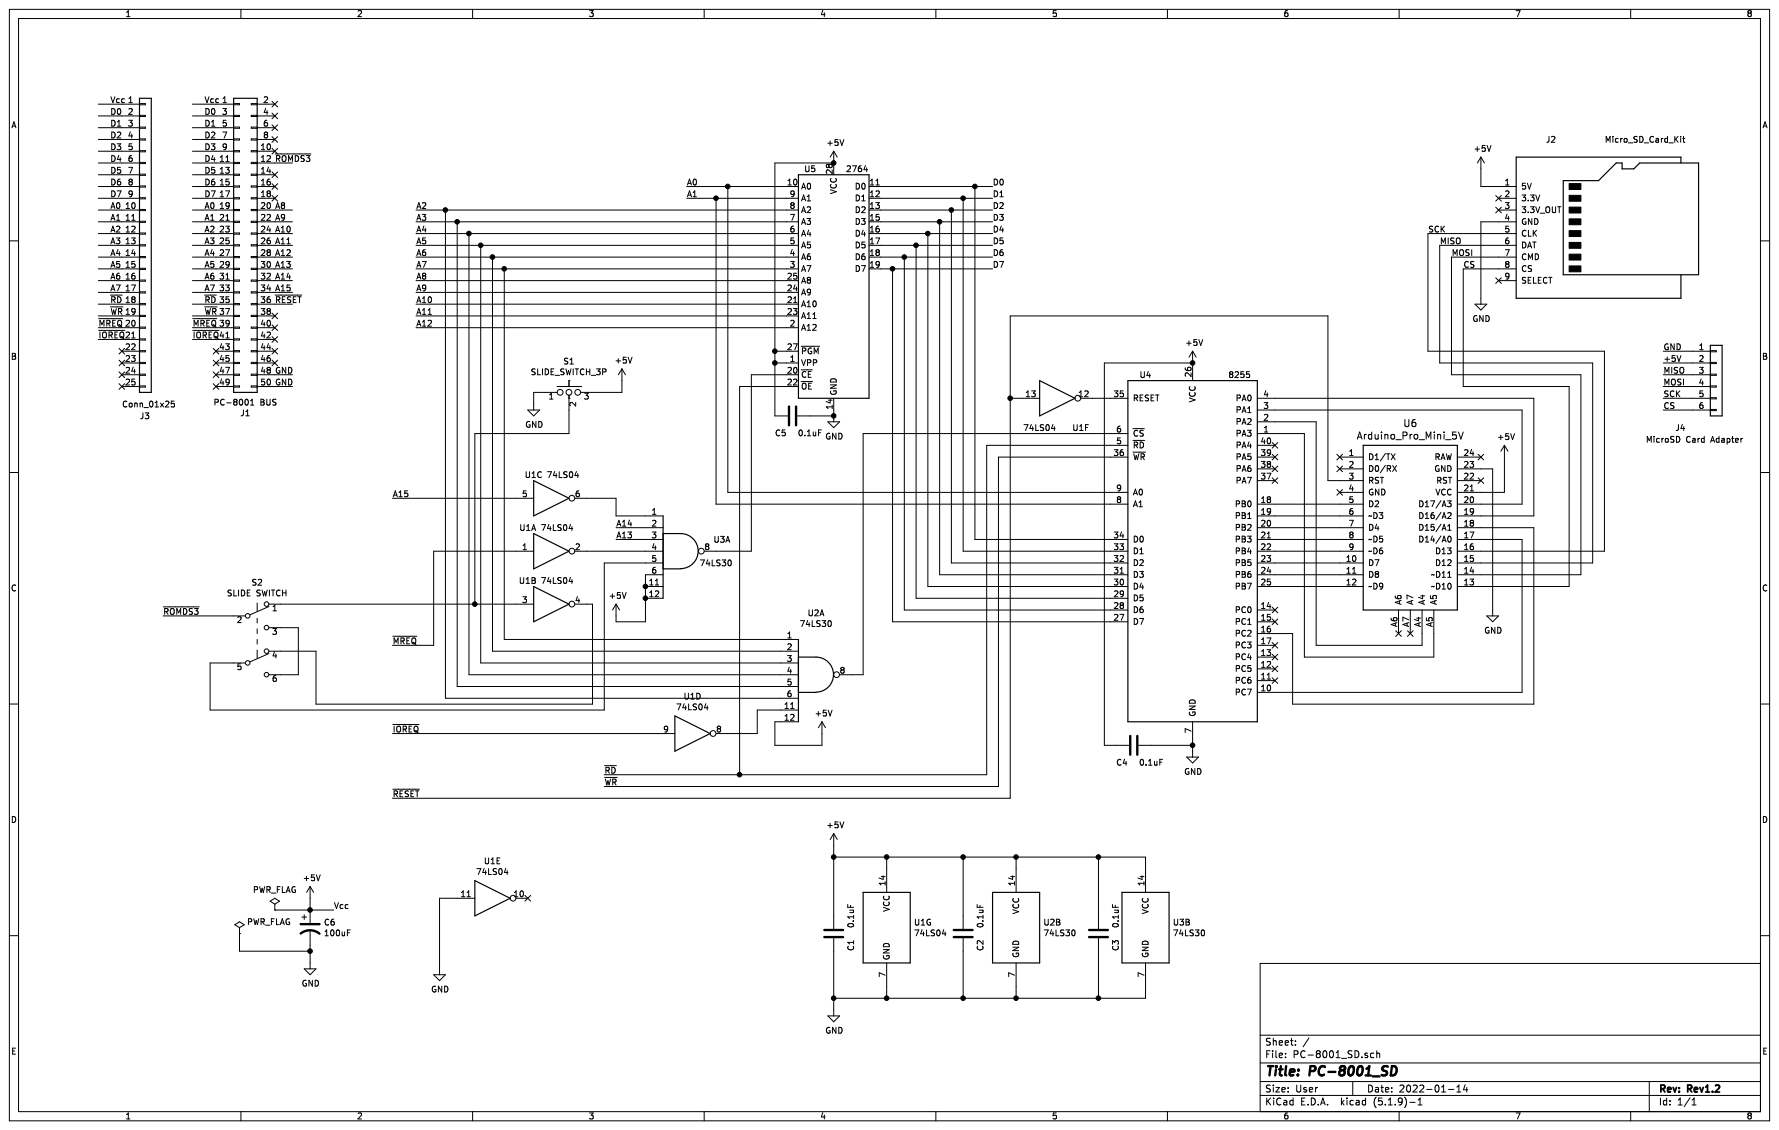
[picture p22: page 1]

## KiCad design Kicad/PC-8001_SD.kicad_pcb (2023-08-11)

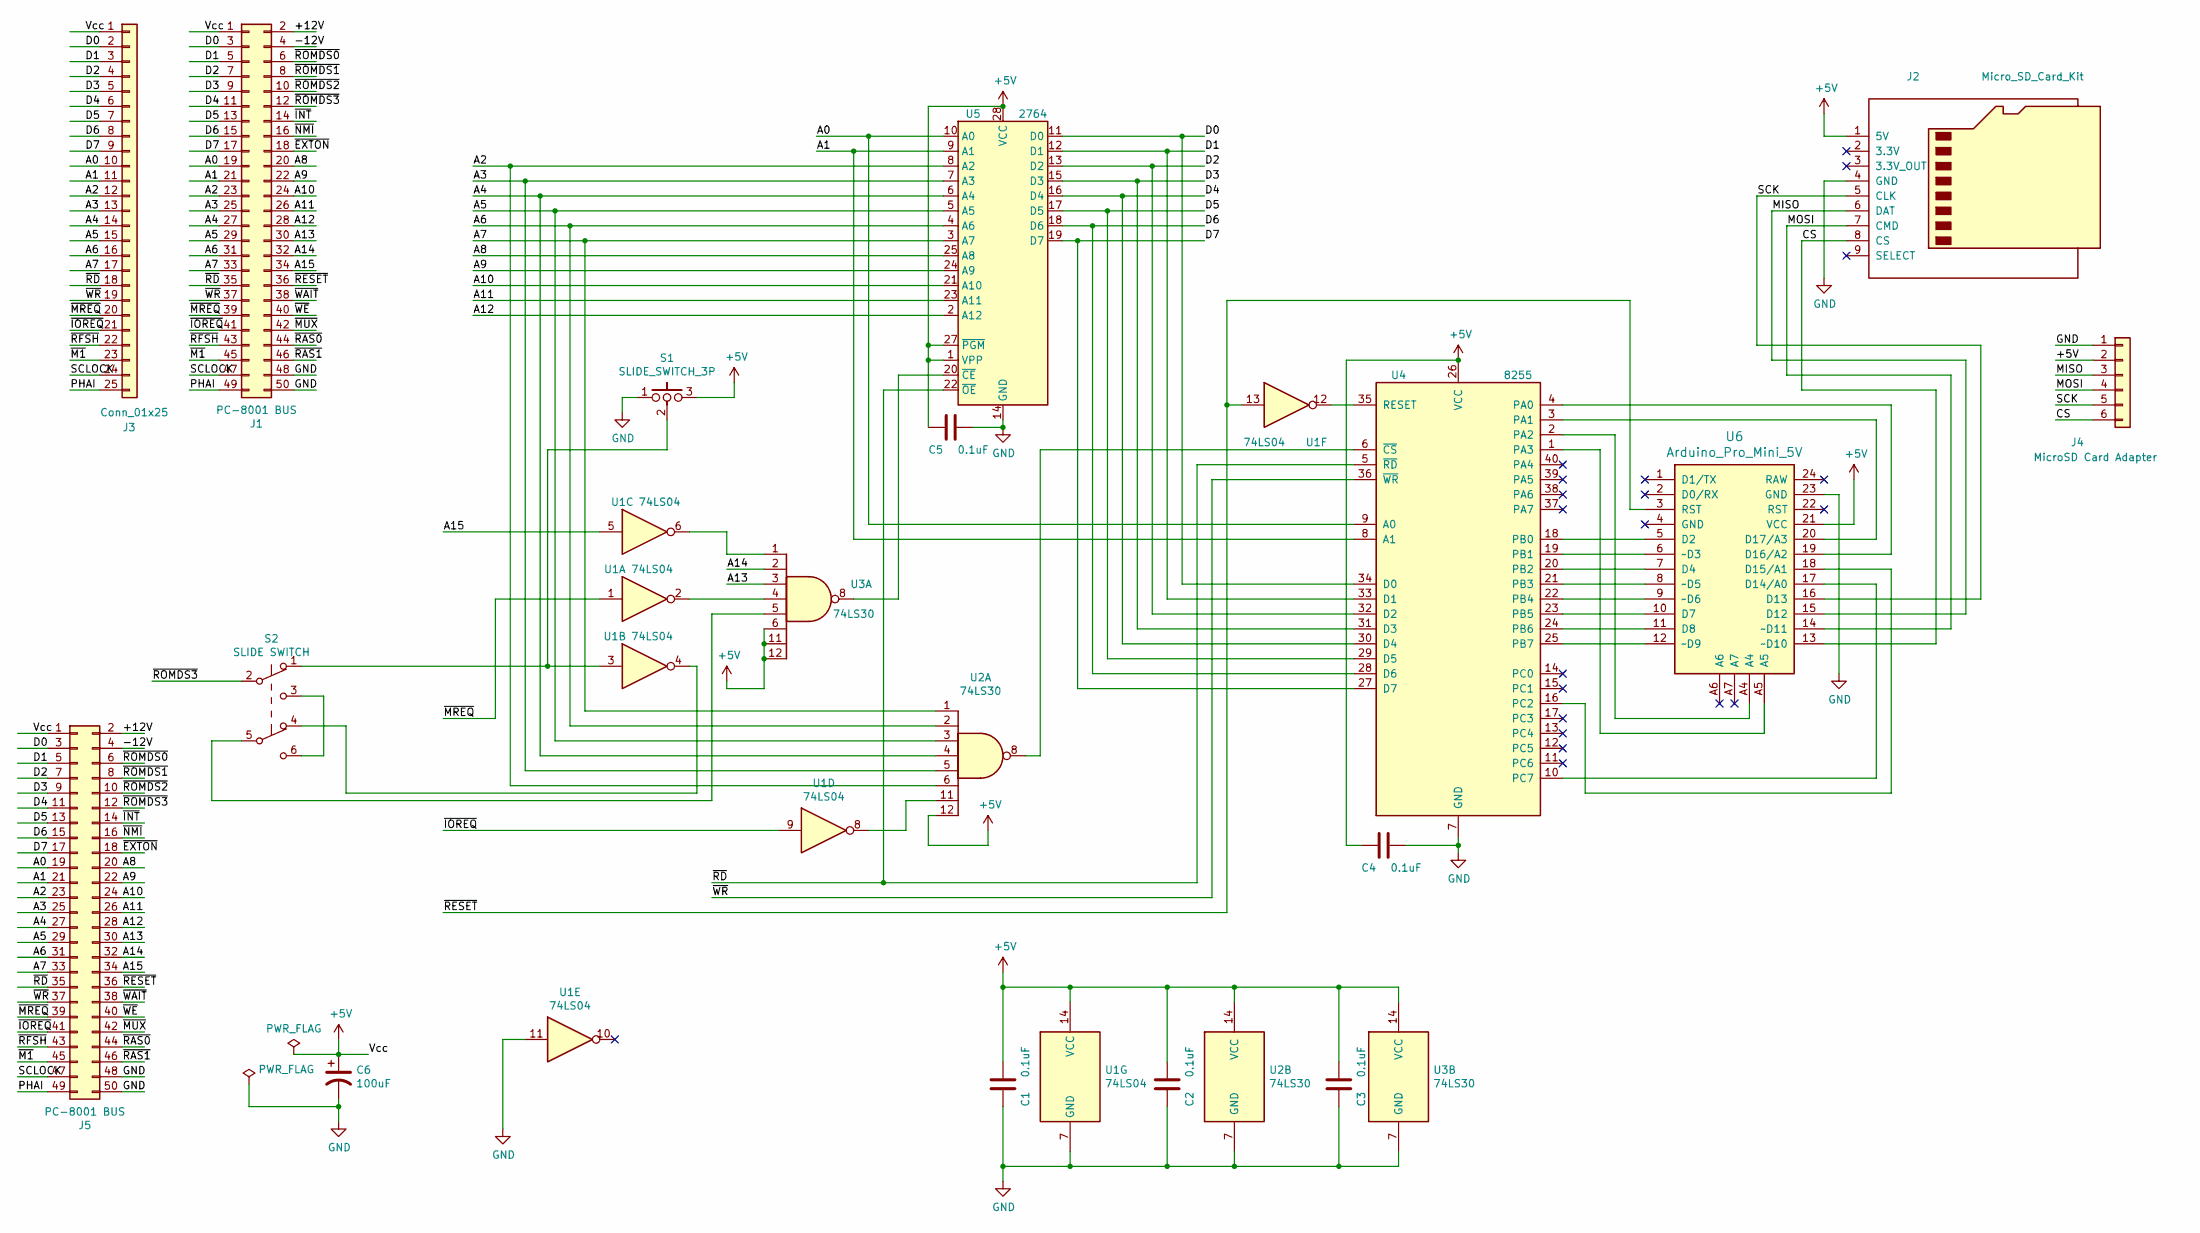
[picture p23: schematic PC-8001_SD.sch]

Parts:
C1, C2, C3, C4, C5: 0.1uF; C_Rect_L4.0mm_W2.5mm_P2.50mm
C6: 100uF; CP_Radial_D5.0mm_P2.50mm
J1: PC-8001 BUS; PinHeader_2x25_P2.54mm_Horizontal
J2: Micro_SD_Card_Kit; AE-microSD-LLCNV
J3: Conn_01x25; PinHeader_1x25_P2.54mm_Vertical
J4: MicroSD Card Adapter; PinSocket_1x06_P2.54mm_Vertical
J5: PC-8001 BUS; PinHeader_2x25_P2.54mm_Vertical
S1: SLIDE_SWITCH_3P; PinHeader_1x03_P2.54mm_Vertical
S2: SLIDE SWITCH; SW_CuK_JS202011CQN_DPDT_Straight
U1: 74LS04; DIP-14_W7.62mm_LongPads
U2, U3: 74LS30; DIP-14_W7.62mm_LongPads
U4: 8255; DIP-40_W15.24mm_LongPads
U5: 2764; DIP-28_W15.24mm_LongPads
U6: Arduino_Pro_Mini_5V; Arduino_Pro_Mini

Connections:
+5V: C1.2, C2.2, C3.2, C4.1, C5.1, C6.1, J1.1, J2.1 (5V), J3.1, J4.2, J5.1, S1.3, U1.14 (VCC), U2.12, U2.14 (VCC), U3.6, U3.11, U3.12, U3.14 (VCC), U4.26 (VCC), U5.1 (VPP), U5.27 (~PGM), U5.28 (VCC), U6.21 (VCC)
/+12V: J1.2, J5.2
/-12V: J1.4, J5.4
/A0: J1.19, J3.10, J5.19, U4.9 (A0), U5.10 (A0)
/A1: J1.21, J3.11, J5.21, U4.8 (A1), U5.9 (A1)
/A2: J1.23, J3.12, J5.23, U2.6, U5.8 (A2)
/A3: J1.25, J3.13, J5.25, U2.5, U5.7 (A3)
/A4: J1.27, J3.14, J5.27, U2.4, U5.6 (A4)
/A5: J1.29, J3.15, J5.29, U2.3, U5.5 (A5)
/A6: J1.31, J3.16, J5.31, U2.2, U5.4 (A6)
/A7: J1.33, J3.17, J5.33, U2.1, U5.3 (A7)
/A8: J1.20, J5.20, U5.25 (A8)
/A9: J1.22, J5.22, U5.24 (A9)
/A10: J1.24, J5.24, U5.21 (A10)
/A11: J1.26, J5.26, U5.23 (A11)
/A12: J1.28, J5.28, U5.2 (A12)
/A13: J1.30, J5.30, U3.3
/A14: J1.32, J5.32, U3.2
/A15: J1.34, J5.34, U1.5
/CS: J2.8 (CS), J4.6, U6.13 (~~D10)
/D0: J1.3, J3.2, J5.3, U4.34 (D0), U5.11 (D0)
/D1: J1.5, J3.3, J5.5, U4.33 (D1), U5.12 (D1)
/D2: J1.7, J3.4, J5.7, U4.32 (D2), U5.13 (D2)
/D3: J1.9, J3.5, J5.9, U4.31 (D3), U5.15 (D3)
/D4: J1.11, J3.6, J5.11, U4.30 (D4), U5.16 (D4)
/D5: J1.13, J3.7, J5.13, U4.29 (D5), U5.17 (D5)
/D6: J1.15, J3.8, J5.15, U4.28 (D6), U5.18 (D6)
/D7: J1.17, J3.9, J5.17, U4.27 (D7), U5.19 (D7)
/MISO: J2.6 (DAT), J4.3, U6.15 (D12)
/MOSI: J2.7 (CMD), J4.4, U6.14 (~~D11)
/PHAI: J1.49, J3.25, J5.49
/SCK: J2.5 (CLK), J4.5, U6.16 (D13)
/SCLOCK: J1.47, J3.24, J5.47
/~EXTON: J1.18, J5.18
/~INT: J1.14, J5.14
/~IOREQ: J1.41, J3.21, J5.41, U1.9
/~M1: J1.45, J3.23, J5.45
/~MREQ: J1.39, J3.20, J5.39, U1.1
/~MUX: J1.42, J5.42
/~NMI: J1.16, J5.16
/~RAS0: J1.44, J5.44
/~RAS1: J1.46, J5.46
/~RD: J1.35, J3.18, J5.35, U4.5 (~RD~), U5.22 (~OE)
/~RESET: J1.36, J5.36, U1.13, U6.3 (RST)
/~RFSH: J1.43, J3.22, J5.43
/~ROMDS0: J1.6, J5.6
/~ROMDS1: J1.8, J5.8
/~ROMDS2: J1.10, J5.10
/~ROMDS3: J1.12, J5.12, S2.2 (B)
/~WAIT: J1.38, J5.38
/~WE: J1.40, J5.40
/~WR: J1.37, J3.19, J5.37, U4.36 (~WR~)
GND: C1.1, C2.1, C3.1, C4.2, C5.2, C6.2, J1.48, J1.50, J2.4 (GND), J4.1, J5.48, J5.50, S1.1, U1.7 (GND), U1.11, U2.7 (GND), U3.7 (GND), U4.7 (GND), U5.14 (GND), U6.23 (GND)
unnamed: S1.2, S2.1 (A), U1.3
unnamed: S2.3 (C), S2.6 (C)
unnamed: S2.4 (A), U1.4
unnamed: S2.5 (B), U3.5
unnamed: U1.2, U3.4
unnamed: U1.6, U3.1
unnamed: U1.8, U2.11
unnamed: U1.12, U4.35 (RESET)
unnamed: U2.8, U4.6 (~CS~)
unnamed: U3.8, U5.20 (~CE)
unnamed: U4.1 (PA3), U6.A5
unnamed: U4.2 (PA2), U6.A4
unnamed: U4.3 (PA1), U6.20 (D17/A3)
unnamed: U4.4 (PA0), U6.19 (D16/A2)
unnamed: U4.10 (PC7), U6.17 (D14/A0)
unnamed: U4.16 (PC2), U6.18 (D15/A1)
unnamed: U4.18 (PB0), U6.5 (D2)
unnamed: U4.19 (PB1), U6.6 (~~D3)
unnamed: U4.20 (PB2), U6.7 (D4)
unnamed: U4.21 (PB3), U6.8 (~~D5)
unnamed: U4.22 (PB4), U6.9 (~~D6)
unnamed: U4.23 (PB5), U6.10 (D7)
unnamed: U4.24 (PB6), U6.11 (D8)
unnamed: U4.25 (PB7), U6.12 (~~D9)

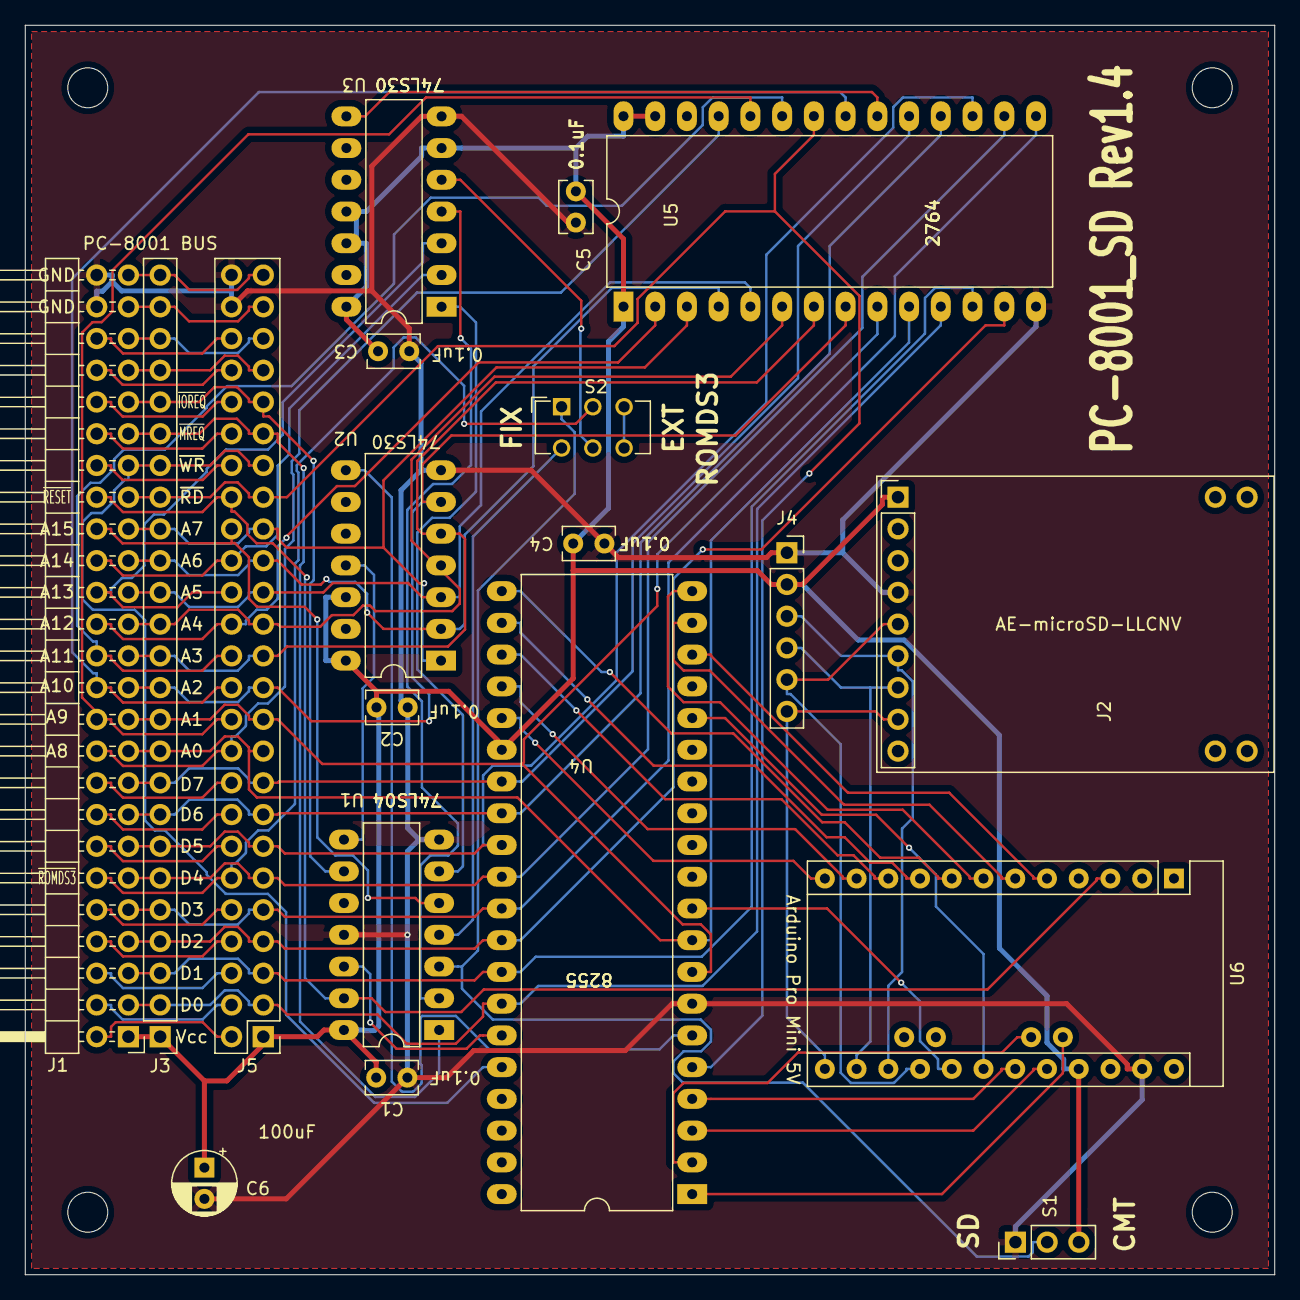
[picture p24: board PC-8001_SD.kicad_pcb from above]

Board: 2 copper layers, 100.0 x 100.0 mm, 23 parts (0 on the bottom side), 77 nets.

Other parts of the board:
MH1, MH2, MH3, MH4: MountingHole_3.2mm_M3

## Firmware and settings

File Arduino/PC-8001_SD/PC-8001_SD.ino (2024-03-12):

// 2024. 3.12 sd-card再挿入時の初期化処理を追加
//
#include "SdFat.h"
#include <SPI.h>
SdFat SD;
unsigned long r_count=0;
unsigned long f_length=0;
char m_name[40];
byte s_data[260];
char f_name[40];
char c_name[40];
char new_name[40];
char w_name[40];
File file,w_file;
unsigned int s_adrs,e_adrs,w_length,w_len1,w_len2,s_adrs1,s_adrs2,b_length;

#define CABLESELECTPIN  (10)
#define CHKPIN          (15)
#define PB0PIN          (2)
#define PB1PIN          (3)
#define PB2PIN          (4)
#define PB3PIN          (5)
#define PB4PIN          (6)
#define PB5PIN          (7)
#define PB6PIN          (8)
#define PB7PIN          (9)
#define FLGPIN          (14)
#define PA0PIN          (16)
#define PA1PIN          (17)
#define PA2PIN          (18)
#define PA3PIN          (19)
// ファイル名は、ロングファイルネーム形式対応
boolean eflg;

void sdinit(void){
  // SD初期化
  if( !SD.begin(CABLESELECTPIN,8) )
  {
////    Serial.println("Failed : SD.begin");
    eflg = true;
  } else {
////    Serial.println("OK : SD.begin");
    eflg = false;
  }
////    Serial.println("START");
}

void setup(){
////    Serial.begin(9600);
// CS=pin10
// pin10 output

  pinMode(CABLESELECTPIN,OUTPUT);
  pinMode( CHKPIN,INPUT);  //CHK
  pinMode( PB0PIN,OUTPUT); //送信データ
  pinMode( PB1PIN,OUTPUT); //送信データ
  pinMode( PB2PIN,OUTPUT); //送信データ
  pinMode( PB3PIN,OUTPUT); //送信データ
  pinMode( PB4PIN,OUTPUT); //送信データ
  pinMode( PB5PIN,OUTPUT); //送信データ
  pinMode( PB6PIN,OUTPUT); //送信データ
  pinMode( PB7PIN,OUTPUT); //送信データ
  pinMode( FLGPIN,OUTPUT); //FLG

  pinMode( PA0PIN,INPUT_PULLUP); //受信データ
  pinMode( PA1PIN,INPUT_PULLUP); //受信データ
  pinMode( PA2PIN,INPUT_PULLUP); //受信データ
  pinMode( PA3PIN,INPUT_PULLUP); //受信データ

  digitalWrite(PB0PIN,LOW);
  digitalWrite(PB1PIN,LOW);
  digitalWrite(PB2PIN,LOW);
  digitalWrite(PB3PIN,LOW);
  digitalWrite(PB4PIN,LOW);
  digitalWrite(PB5PIN,LOW);
  digitalWrite(PB6PIN,LOW);
  digitalWrite(PB7PIN,LOW);
  digitalWrite(FLGPIN,LOW);

  delay(1500);
//sd_waopen sd_wnopen sd_wdirectでSAVE用ファイル名を指定なくSAVEされた場合のデフォルトファイル名を設定
  strcpy(w_name,"default.dat");

  sdinit();
}

//4BIT受信
byte rcv4bit(void){
//HIGHになるまでループ
  while(digitalRead(CHKPIN) != HIGH){
  }
//受信
  byte j_data = digitalRead(PA0PIN)+digitalRead(PA1PIN)*2+digitalRead(PA2PIN)*4+digitalRead(PA3PIN)*8;
//FLGをセット
  digitalWrite(FLGPIN,HIGH);
//LOWになるまでループ
  while(digitalRead(CHKPIN) == HIGH){
  }
//FLGをリセット
  digitalWrite(FLGPIN,LOW);
  return(j_data);
}

//1BYTE受信
byte rcv1byte(void){
  byte i_data = 0;
  i_data=rcv4bit()*16;
  i_data=i_data+rcv4bit();
  return(i_data);
}

//1BYTE送信
void snd1byte(byte i_data){
//下位ビットから8ビット分をセット
  digitalWrite(PB0PIN,(i_data)&0x01);
  digitalWrite(PB1PIN,(i_data>>1)&0x01);
  digitalWrite(PB2PIN,(i_data>>2)&0x01);
  digitalWrite(PB3PIN,(i_data>>3)&0x01);
  digitalWrite(PB4PIN,(i_data>>4)&0x01);
  digitalWrite(PB5PIN,(i_data>>5)&0x01);
  digitalWrite(PB6PIN,(i_data>>6)&0x01);
  digitalWrite(PB7PIN,(i_data>>7)&0x01);
  digitalWrite(FLGPIN,HIGH);
//HIGHになるまでループ
  while(digitalRead(CHKPIN) != HIGH){
  }
  digitalWrite(FLGPIN,LOW);
//LOWになるまでループ
  while(digitalRead(CHKPIN) == HIGH){
  }
}

//小文字->大文字
char upper(char c){
  if('a' <= c && c <= 'z'){
    c = c - ('a' - 'A');
  }
  return c;
}

//ファイル名の最後が「.cmt」でなければ付加
void addcmt(char *f_name,char *m_name){
  unsigned int lp1=0;
  while (f_name[lp1] != 0x00){
    m_name[lp1] = f_name[lp1];
    lp1++;
  }
  if (f_name[lp1-4]!='.' ||
    ( f_name[lp1-3]!='C' &&
      f_name[lp1-3]!='c' ) ||
    ( f_name[lp1-2]!='M' &&
      f_name[lp1-2]!='m' ) ||
    ( f_name[lp1-1]!='T' &&
      f_name[lp1-1]!='t' ) ){
         m_name[lp1++] = '.';
         m_name[lp1++] = 'c';
         m_name[lp1++] = 'm';
         m_name[lp1++] = 't';
  }
  m_name[lp1] = 0x00;
}

//比較文字列取得 32+1文字まで取得、ただしダブルコーテーションは無視する
void receive_name(char *f_name){
char r_data;
  unsigned int lp2 = 0;
  for (unsigned int lp1 = 0;lp1 <= 32;lp1++){
    r_data = rcv1byte();
    if (r_data != 0x22){
      f_name[lp2] = r_data;
      lp2++;
    }
  }
}


// MONITOR Lコマンド .CMT LOAD
void cmt_load(void){
  boolean flg = false;
//DOSファイル名取得
  receive_name(m_name);
//ファイル名の指定があるか
  if (m_name[0]!=0x00){
    addcmt(m_name,f_name);
  
//指定があった場合
//ファイルが存在しなければERROR
    if (SD.exists(f_name) == true){
//ファイルオープン
      file = SD.open( f_name, FILE_READ );

      if( true == file ){
//f_length設定、r_count初期化
        f_length = file.size();
        r_count = 0;
//状態コード送信(OK)
        snd1byte(0x00);
        flg = true;
      } else {
        snd1byte(0xf0);
        sdinit();
        flg = false;
      }
    }else{
      snd1byte(0xf1);
      sdinit();
      flg = false;
    }
  }else{
//ファイル名の指定がなかった場合
//ファイルエンドになっていないか
    if (f_length > r_count){
      snd1byte(0x00);
      flg = true;
    }else{
      snd1byte(0xf1);
      flg = false;
    }
  }

//良ければファイルエンドまで読み込みを続行する
  if (flg == true) {
    int rdata = 0;
      
//ヘッダーが出てくるまで読み飛ばし
    while (rdata != 0x3a && rdata != 0xd3) {
      rdata = file.read();
      r_count++;
    }
//ヘッダー送信
    snd1byte(rdata);

//ヘッダーが0x3aなら続行、違えばエラー
    if (rdata == 0x3a){
//START ADDRESS HIを送信
      s_adrs1 = file.read();
      r_count++;
      snd1byte(s_adrs1);

//START ADDRESS LOを送信
      s_adrs2 = file.read();
      r_count++;
      snd1byte(s_adrs2);
      s_adrs = s_adrs1*256+s_adrs2;

//CHECK SUMを送信
      rdata = file.read();
      r_count++;
      snd1byte(rdata);

//HEADERを送信
      rdata = file.read();
      r_count++;
      snd1byte(rdata);

//データ長を送信
      b_length = file.read();
      r_count++;
      snd1byte(b_length);
      
//データ長が0x00でない間ループする
      while (b_length !=0x00) {
        for (unsigned int lp1 = 0;lp1 <= b_length;lp1++){
//実データを読み込んで送信
          rdata = file.read();
          r_count++;
          snd1byte(rdata);
      }
//CHECK SUMを送信
        rdata = file.read();
        r_count++;
        snd1byte(rdata);
//データ長を送信
        b_length = file.read();
        r_count++;
        snd1byte(b_length);
      }
//データ長が0x00だった時の後処理
//CHECK SUMを送信
      rdata = file.read();
      r_count++;
      snd1byte(rdata);

//ファイルエンドに達していたらFILE CLOSE
      if (f_length == r_count){
        file.close();
      }
    }else{
        file.close();
    }
  }        
}

//BASICプログラムのLOAD処理
void bas_load(void){
  boolean flg = false;
//DOSファイル名取得
  receive_name(m_name);
//ファイル名の指定があるか
  if (m_name[0]!=0x00){
    addcmt(m_name,f_name);
  
//指定があった場合
//ファイルが存在しなければERROR
    if (SD.exists(f_name) == true){
//ファイルオープン
      file = SD.open( f_name, FILE_READ );
      if( true == file ){
//f_length設定、r_count初期化
        f_length = file.size();
        r_count = 0;
//状態コード送信(OK)
        snd1byte(0x00);
        flg = true;
      } else {
        snd1byte(0xf0);
        sdinit();
        flg = false;
      }
    }else{
      snd1byte(0xf1);
      sdinit();
      flg = false;
    }
  } else{
//ファイル名の指定がなかった場合
//ファイルエンドになっていないか
    if (f_length > r_count){
      snd1byte(0x00);
      flg = true;
    }else{
      snd1byte(0xf1);
      flg = false;
    }
  }
//良ければファイルエンドまで読み込みを続行する
  if (flg == true){
    int rdata = 0;
      
//ヘッダーが出てくるまで読み飛ばし
    while (rdata != 0x3a && rdata != 0xd3) {
      rdata = file.read();
      r_count++;
    }
//ヘッダー送信
    snd1byte(rdata);
//ヘッダーが0xd3なら続行、違えばエラー
    if (rdata == 0xd3){
      while (rdata == 0xd3) {
        rdata = file.read();
        r_count++;
      }

//実データ送信
      int zcnt = 0;
      int zdata = 1;

      snd1byte(rdata);

//0x00が11個続くまで読み込み、送信
      while (zcnt < 11) {
        rdata = file.read();
        r_count++;
        snd1byte(rdata);
        if (rdata == 0x00){
          zcnt++;
          if (zdata != 0){
            zcnt = 0;
          }
        }
        zdata = rdata;
      }

//ファイルエンドに達していたらFILE CLOSE
      if (f_length == r_count){
        file.close();
      }      
    }else{
        file.close();
    }
  }
}


void w_body(void){
byte r_data,csum;
//ヘッダー 0x3A書き込み
  w_file.write(char(0x3A));
//スタートアドレス取得、書き込み
  s_adrs1 = rcv1byte();
  s_adrs2 = rcv1byte();
  w_file.write(s_adrs2);
  w_file.write(s_adrs1);
//CHECK SUM計算、書き込み
  csum = 0 - (s_adrs1 + s_adrs2);
  w_file.write(csum);
//スタートアドレス算出
  s_adrs = s_adrs1+s_adrs2*256;
//エンドアドレス取得
  s_adrs1 = rcv1byte();
  s_adrs2 = rcv1byte();
//エンドアドレス算出
  e_adrs = s_adrs1+s_adrs2*256;
//ファイル長算出、ブロック数算出
  w_length = e_adrs - s_adrs + 1;
  w_len1 = w_length / 255;
  w_len2 = w_length % 255;

//実データ受信、書き込み
//0xFFブロック
  while (w_len1 > 0){
    w_file.write(char(0x3A));
    w_file.write(char(0xFF));
    csum = 0xff;
    for (unsigned int lp1 = 1;lp1 <= 255;lp1++){
      r_data = rcv1byte();
      w_file.write(r_data);
      csum = csum + r_data;
    }
//CHECK SUM計算、書き込み
    csum = 0 - csum;
    w_file.write(csum);
    w_len1--;
  }

//端数ブロック処理
  if (w_len2 > 0){
    w_file.write(char(0x3A));
    w_file.write(w_len2);
    csum = w_len2;
    for (unsigned int lp1 = 1;lp1 <= w_len2;lp1++){
      r_data = rcv1byte();
      w_file.write(r_data);
      csum = csum + r_data;
      
    }
//CHECK SUM計算、書き込み
    csum = 0 - csum;
    w_file.write(csum);
  }
  w_file.write(char(0x3A));
  w_file.write(char(0x00));
  w_file.write(char(0x00));
}

// MONITOR Wコマンド .CMT SAVE
void cmt_save(void){
byte r_data,csum;
//DOSファイル名取得
  receive_name(m_name);
//ファイル名の指定が無ければエラー
  if (m_name[0]!=0x00){
    addcmt(m_name,f_name);
  
  if( true == w_file ){
    w_file.close();
  }
//ファイルが存在すればdelete
    if (SD.exists(f_name) == true){
      SD.remove(f_name);
    }
//ファイルオープン
    w_file = SD.open( f_name, FILE_WRITE );
    if( true == w_file ){
//状態コード送信(OK)
      snd1byte(0x00);
      w_body();
      w_file.close();
    }else{
      snd1byte(0xf0);
      sdinit();
    }
  }else{
    snd1byte(0xf6);
    sdinit();
  }
}

//BASICプログラムのSAVE処理
void bas_save(void){
unsigned int lp1;

//DOSファイル名取得
  receive_name(m_name);
//ファイル名の指定が無ければエラー
  if (m_name[0]!=0x00){
    addcmt(m_name,f_name);
  
  if( true == w_file ){
    w_file.close();
  }
//ファイルが存在すればdelete
    if (SD.exists(f_name) == true){
      SD.remove(f_name);
    }
//ファイルオープン
    w_file = SD.open( f_name, FILE_WRITE );
    if( true == w_file ){
//状態コード送信(OK)
      snd1byte(0x00);

//スタートアドレス取得
      s_adrs1 = rcv1byte();
      s_adrs2 = rcv1byte();
//スタートアドレス算出
      s_adrs = s_adrs1+s_adrs2*256;
//エンドアドレス取得
      s_adrs1 = rcv1byte();
      s_adrs2 = rcv1byte();
//エンドアドレス算出
      e_adrs = s_adrs1+s_adrs2*256;
//ヘッダー 0xD3 x 9回書き込み
      for (lp1 = 0;lp1 <= 9;lp1++){
        w_file.write(char(0xD3));
      }
//DOSファイル名の先頭6文字をファイルネームとして書き込み
      for (lp1 = 0;lp1 <= 5;lp1++){
        w_file.write(m_name[lp1]);
      }
//実データ (e_adrs - s_adrs +1)を受信、書き込み
      for (lp1 = s_adrs;lp1 <= e_adrs;lp1++){
        w_file.write(rcv1byte());
      }
//終了 0x00 x 9回書き込み
      for (lp1 = 1;lp1 <= 9;lp1++){
        w_file.write(char(0x00));
      }
      w_file.close();
    } else {
      snd1byte(0xf0);
      sdinit();
    }
  }else{
    snd1byte(0xf1);
    sdinit();
  }
}

//BASICプログラムのKILL処理
void bas_kill(void){
unsigned int lp1;

//DOSファイル名取得
  receive_name(m_name);
//ファイル名の指定が無ければエラー
  if (m_name[0]!=0x00){
    addcmt(m_name,f_name);
  
//状態コード送信(OK)
      snd1byte(0x00);
//ファイルが存在すればdelete
    if (SD.exists(f_name) == true){
      SD.remove(f_name);
//状態コード送信(OK)
      snd1byte(0x00);
    }else{
      snd1byte(0xf1);
      sdinit();
    }
  }else{
    snd1byte(0xf1);
    sdinit();
  }
}

//5F9EH CMT 1Byte読み込み処理の代替、OPENしているファイルの続きから1Byteを読み込み、送信
void cmt_5f9e(void){
  int rdata = file.read();
  r_count++;
  snd1byte(rdata);
//ファイルエンドまで達していればFILE CLOSE
  if (f_length == r_count){
    file.close();
  }      
}

//read file open
void sd_ropen(void){
  receive_name(f_name);
//ファイルが存在しなければERROR
  if (SD.exists(f_name) == true){
//ファイルオープン
    file = SD.open( f_name, FILE_READ );
    if( true == file ){
//f_length設定、r_count初期化
      f_length = file.size();
      r_count = 0;
//状態コード送信(OK)
      snd1byte(0x00);
    } else {
      snd1byte(0xf0);
      sdinit();
    }
  }else{
    snd1byte(0xf1);
    sdinit();
  }
}

//write file append open
void sd_waopen(void){
  receive_name(w_name);
//ファイルオープン
  if( true == w_file ){
    w_file.close();
  }
  w_file = SD.open( w_name, FILE_WRITE );
  if( true == w_file ){
//状態コード送信(OK)
    snd1byte(0x00);
  } else {
    snd1byte(0xf0);
    sdinit();
  }
}

//write file new open
void sd_wnopen(void){
  receive_name(w_name);
  if( true == w_file ){
    w_file.close();
  }
//ファイルが存在すればdelete
  if (SD.exists(w_name) == true){
    SD.remove(w_name);
  }
//ファイルオープン
  w_file = SD.open( w_name, FILE_WRITE );
  if( true == w_file ){
//状態コード送信(OK)
    snd1byte(0x00);
  } else {
    snd1byte(0xf0);
    sdinit();
  }
}

//write 1byte 5F2FH代替
void sd_w1byte(void){
  int rdata = rcv1byte();
  if( true == w_file ){
    w_file.write(rdata);
//状態コード送信(OK)
    snd1byte(0x00);
  } else {
    snd1byte(0xf0);
    sdinit();
  }
}

//5ED9H代替
void sd_wdirect(void){
  if( true == w_file ){
    w_body();
    w_file.close();
//状態コード送信(OK)
    snd1byte(0x00);
  }else{
    snd1byte(0xf0);
    sdinit();
  }
}

//write file close
void sd_wclose(void){
    w_file.close();
}

// SD-CARDのFILELIST
void dirlist(void){
//比較文字列取得 32+1文字まで

  for (unsigned int lp1 = 0;lp1 <= 32;lp1++){
    c_name[lp1] = rcv1byte();
  }
//
  File file = SD.open( "/" );
  if( true == file ){
//状態コード送信(OK)
    snd1byte(0x00);

    File entry =  file.openNextFile();
    int cntl2 = 0;
    unsigned int br_chk =0;
    int page = 1;
//全件出力の場合には16件出力したところで一時停止、キー入力により継続、打ち切りを選択
    while (br_chk == 0) {
      if(entry){
        entry.getName(f_name,36);
        unsigned int lp1=0;
//一件送信
//比較文字列でファイルネームを先頭10文字まで比較して一致するものだけを出力
        if (f_match(f_name,c_name)){
          while (lp1<=36 && f_name[lp1]!=0x00){
          snd1byte(upper(f_name[lp1]));
          lp1++;
          }
          snd1byte(0x0D);
          snd1byte(0x00);
          cntl2++;
        }
      }
      if (!entry || cntl2 > 15){
//継続・打ち切り選択指示要求
        snd1byte(0xfe);

//選択指示受信(0:継続 B:前ページ 以外:打ち切り)
        br_chk = rcv1byte();
//前ページ処理
        if (br_chk==0x42){
//先頭ファイルへ
          file.rewindDirectory();
//entry値更新
          entry =  file.openNextFile();
//もう一度先頭ファイルへ
          file.rewindDirectory();
          if(page <= 2){
//現在ページが1ページ又は2ページなら1ページ目に戻る処理
            page = 0;
          } else {
//現在ページが3ページ以降なら前々ページまでのファイルを読み飛ばす
            page = page -2;
            cntl2=0;
            while(cntl2 < page*16){
              entry =  file.openNextFile();
              if (f_match(f_name,c_name)){
                cntl2++;
              }
            }
          }
          br_chk=0;
        }
        page++;
        cntl2 = 0;
      }
//ファイルがまだあるなら次読み込み、なければ打ち切り指示
      if (entry){
        entry =  file.openNextFile();
      }else{
        br_chk=1;
      }
//FDLの結果が18件未満なら継続指示要求せずにそのまま終了
      if (!entry && cntl2 < 16 && page ==1){
        break;
      }
    }
//処理終了指示
    snd1byte(0xFF);
    snd1byte(0x00);
  }else{
    snd1byte(0xf1);
  }
}

//f_nameとc_nameをc_nameに0x00が出るまで比較
//FILENAME COMPARE
boolean f_match(char *f_name,char *c_name){
  boolean flg1 = true;
  unsigned int lp1 = 0;
  while (lp1 <=32 && c_name[0] != 0x00 && flg1 == true){
    if (upper(f_name[lp1]) != c_name[lp1]){
      flg1 = false;
    }
    lp1++;
    if (c_name[lp1]==0x00){
      break;
    }
  }
  return flg1;
}

void loop()
{
  digitalWrite(PB0PIN,LOW);
  digitalWrite(PB1PIN,LOW);
  digitalWrite(PB2PIN,LOW);
  digitalWrite(PB3PIN,LOW);
  digitalWrite(PB4PIN,LOW);
  digitalWrite(PB5PIN,LOW);
  digitalWrite(PB6PIN,LOW);
  digitalWrite(PB7PIN,LOW);
  digitalWrite(FLGPIN,LOW);
//コマンド取得待ち
////    Serial.println("COMMAND WAIT");
  byte cmd = rcv1byte();
////    Serial.println(cmd,HEX);
  if (eflg == false){
    switch(cmd) {
//70h:PC-8001 CMTファイル SAVE
      case 0x70:
////    Serial.println("CMT SAVE START");
//状態コード送信(OK)
        snd1byte(0x00);
        cmt_save();
        break;
//71h:PC-8001 CMTファイル LOAD
      case 0x71:
////    Serial.println("CMT LOAD START");
//状態コード送信(OK)
        snd1byte(0x00);
        cmt_load();
        break;
//72h:PC-8001 5F9EH READ ONE BYTE FROM CMT
      case 0x72:
////    Serial.println("CMT_5F9E START");
//状態コード送信(OK)
        snd1byte(0x00);
        cmt_5f9e();
        break;
//73h:PC-8001 CMTファイル BASIC LOAD
      case 0x73:
////    Serial.println("CMT BASIC LOAD START");
//状態コード送信(OK)
        snd1byte(0x00);
        bas_load();
        break;
//74h:PC-8001 CMTファイル BASIC SAVE
      case 0x74:
////    Serial.println("CMT BASIC SAVE START");
//状態コード送信(OK)
        snd1byte(0x00);
        bas_save();
        break;
//75h:PC-8001 CMTファイル KILL
      case 0x75:
////    Serial.println("CMT KILL START");
//状態コード送信(OK)
        snd1byte(0x00);
        bas_kill();
        break;
//76h:PC-8001 SD FILE READ OPEN
      case 0x76:
////    Serial.println("SD FILE READ OPEN START");
//状態コード送信(OK)
        snd1byte(0x00);
        sd_ropen();
        break;
//77h:PC-8001 SD FILE WRITE APPEND OPEN
      case 0x77:
////    Serial.println("SD FILE WRITE APPEND OPEN START");
//状態コード送信(OK)
        snd1byte(0x00);
        sd_waopen();
        break;
//78h:PC-8001 SD FILE WRITE 1Byte
      case 0x78:
////    Serial.println("SD FILE WRITE 1Byte START");
//状態コード送信(OK)
        snd1byte(0x00);
        sd_w1byte();
        break;
//79h:PC-8001 SD FILE WRITE NEW OPEN
      case 0x79:
////    Serial.println("SD FILE WRITE NEW OPEN START");
//状態コード送信(OK)
        snd1byte(0x00);
        sd_wnopen();
        break;
//7Ah:PC-8001 SD WRITE 5ED9H
      case 0x7A:
////    Serial.println("SD WRITE 5ED9H START");
//状態コード送信(OK)
        snd1byte(0x00);
        sd_wdirect();
        break;
//7Bh:PC-8001 SD FILE WRITE CLOSE
      case 0x7B:
////    Serial.println("SD FILE WRITE CLOSE START");
//状態コード送信(OK)
        snd1byte(0x00);
        sd_wclose();
        break;

//83hでファイルリスト出力
      case 0x83:
////    Serial.println("FILE LIST START");
//状態コード送信(OK)
        snd1byte(0x00);
        sdinit();
        dirlist();
        break;
      default:
//状態コード送信(CMD ERROR)
        snd1byte(0xF4);
    }
  } else {
//状態コード送信(ERROR)
    snd1byte(0xF0);
    sdinit();
  }
}
